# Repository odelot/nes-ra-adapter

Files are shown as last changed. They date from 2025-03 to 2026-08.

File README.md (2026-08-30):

# NES RA Adapter Project


Repository of the **NES RetroAchievements Adapter** project – a maker initiative with a "cyberpunk western" style that transforms the physical NES console (released in 1985) by adding Internet connectivity and achievement functionality, supported by the amazing RetroAchievements community.

<p align="center">
  <a href="https://youtu.be/u1GWOFgOU88">
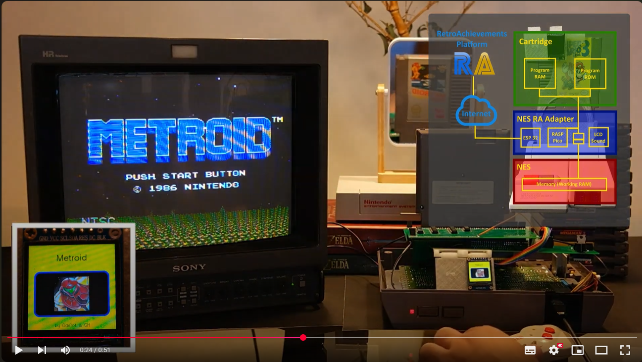
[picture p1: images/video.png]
    
  </a>
</p>

**Now you don't need to open your console!!!**

<p align="center">  
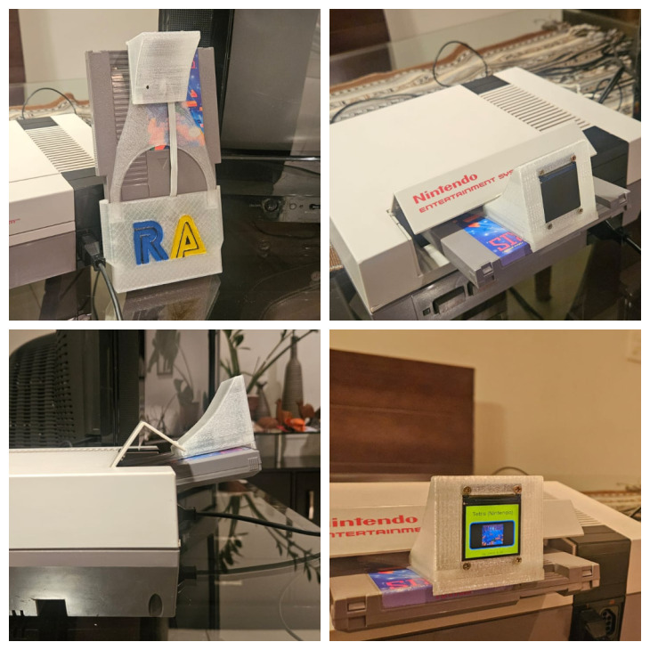
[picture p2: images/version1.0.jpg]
      
</p>

**Famicom version by mi213!**

<p align="center">  
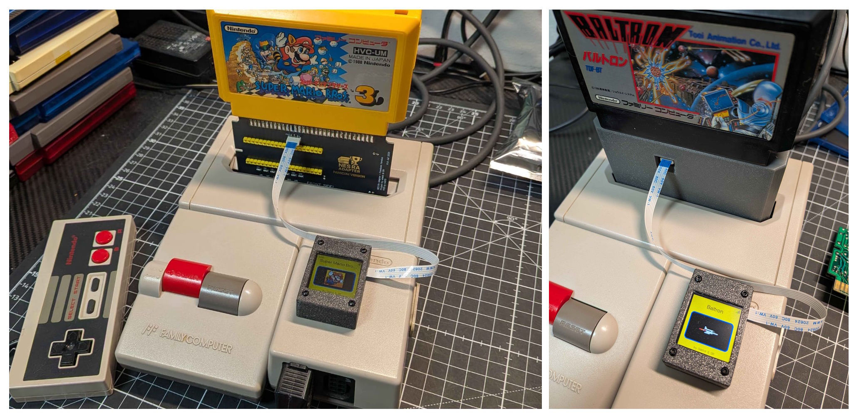
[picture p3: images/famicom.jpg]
      
</p>

---

## Table of Contents

- [Disclaimer](#disclaimer)
- [Introduction](#introduction)
- [Getting Started (How to Build)](#getting-started--how-to-build)
- [Architecture and Functionality](#architecture-and-functionality)
- [Limitations](#limitations)
- [General Information](#general-information)
- [Version History](#version-history)
- [Contributions](#contributions)
- [License](#license)
- [FAQ](#faq)
- [Acknowledgments](#acknowledgments)
- [Similar Projects](#similar-projects)

---

## Disclaimer

The project is not responsible for any use or damage it may cause. Build and use it at your own risk. This is a **PROTOTYPE** that works but still needs to evolve into a final version—with revised hardware, extensive testing, and easy replication. We want everyone to be able to build and use this prototype, but only attempt it if you know what you're doing.

---

## Introduction

The **NES RA Adapter** transforms your original NES console into an interactive, Internet-connected machine, allowing real-time achievement unlocking through the RetroAchievements platform. Inspired by the Game Genie with a touch of cyberpunk western, the adapter:
- **Identifies the game** by reading the cartridge (via CRC calculation).
- **Monitors the console's memory** to detect events and achievements.
- **Provides connectivity and interface** through a TFT screen, buzzer, and smartphone configuration.

### Repository Organization

- **nes-pico-firmware**: source code for the firmware used on the Raspberry Pi Pico (Chinese purple board).
- **nes-esp-firmware**: source code for the firmware used on the ESP32 C3 Super Mini.
- **hardware**: schematics and Gerber files for the v1.0 boards (NES 72-pin by GH and Famicom 60-pin by mi213), plus the old v0.1/v0.2 prototype PCBs used during development.
- **3d parts**: STL files for the modeled case, inspired by the Game Genie (NES 72-pin and Famicom 60-pin designs).
- **misc**ellaneous: auxiliary tool and files (LCD mirror Web App / CRC32<->RA Hash map creator / AWS Lambda to shrink RA response / TFT config).

---

## Getting Started / How to Build

### Acquire the Parts

#### Board 1

| Part Name | Quantity | 
|---|---|
| NES 72-pin slot* | 1x |
| SN74LVC1G3157DBVR | 26x |
| Raspberry Pi Pico (purple board) | 1x |
| Flat cable 20cm 1mm reverse 5pin | 1x |
| FFC & FPC Connectors 1.0 FFC Non ZIF SMT 5 pin - MOLEX 52808-0570 | 1x |
| PCB set | 1x |
| Electrolytic capacitor 10µF 16V | 3x |

\* for the Famicom board, use a 60-pin slot instead

#### Board 2 - PTH (Pin Through-Hole)

| Part Name | Quantity |
|---|---|
| ESP32 C3 Supermini PLUS (with external antenna) | 1x |
| 1.3 inch LCD 240x240 ST7789 with 7 pins | 1x |
| Passive Buzzer 16 ohms ac/2khz + Transistor BC548 | 1x |
| FFC & FPC Connectors 1.0 FFC Non ZIF SMT 5 pin - MOLEX 52808-0570 | 1x |
| PCB set | 1x |
| Electrolytic capacitor 10µF 16V | 1x |
| 1k ohm resistor (R1) | 1x |
| 10k ohm resistor (R2) | 1x |
| Push Button Switch 6x6x6 | 1x |
| 90º degree female header pins (to connect the LCD 7 pins) | 1x |
| 100 ohm resistor (R3 and R4) - optional | 2x |
| Bi-color LED (Green / Red, Common Cathode) - optional | 1x |

#### Board 2 - SMD (Surface Mount Device)

This is the alternative board 2 designed by mi213. It is the one required by his 3D case designs. See the BOM with the SMD components [here](<hardware/Famicom - v1.0 - by mi213/BOM-board2-famicom-v1.0 - by mi213.csv>) (the same board 2 is used by the NES and the Famicom versions).

#### 3d parts 

| Part Name | Quantity |
|---|---|
| 3d printed parts | 1x |
| M2 screw 6mm flat head with nut | 10x |
| M2 screw 10mm cylinder head | 4x |
| M2 length 3 mm (3.2 mm OD) heat-set inserts (for mi213 design) | 4x |

The STL files are in [3d-parts/STL/](3d-parts/STL/), organized by console and designer:
  - [NES - 72pin / 20250911 - odelot design](<3d-parts/STL/NES - 72pin/20250911 - odelot design>) → front-loader and top-loader cases for the through-hole board 2
  - [NES - 72pin / 20260811 - mi213 design](<3d-parts/STL/NES - 72pin/20260811 - mi213 design>) → front-loader and top-loader cases, require mi213's SMD board 2
  - [Famicom - 60pin / 20260811 - mi213 design](<3d-parts/STL/Famicom - 60pin/20260811 - mi213 design>) → Famicom case, requires mi213's SMD board 2

The heat-set inserts are only needed for the mi213 designs.

### Assemble the Circuit

Starting from version 1.0, thanks to GH’s custom boards, you no longer need to open your console to use the adapter. Combined with the 3D-printed case I designed, the adapter works just like a GameGenie,  simply plug it into the cartridge slot and you’re ready to go. A dedicated case for the top-loader model is also available.

Since 2026-08 there is also a **Famicom (60-pin) version of the boards and improved case designs, made by mi213** thanks! ❤️ The hardware files are organized like this:
  - [hardware/NES v1.0 - by GH/](<hardware/NES v1.0 - by GH>) → Gerbers for the NES 72-pin boards 1 and 2
  - [hardware/Famicom - v1.0 - by mi213/](<hardware/Famicom - v1.0 - by mi213>) → Gerbers for the Famicom 60-pin boards 1 and 2, plus the SMD BOM for board 2
  - [hardware/schematics/](hardware/schematics/) → schematics for board 1 and board 2

**Assembly Video Guide (with timecode)** - [https://www.youtube.com/watch?v=4uHbj2ckqv0](https://www.youtube.com/watch?v=4uHbj2ckqv0)
<br/>&nbsp;&nbsp;&nbsp;&nbsp; **\\-** Be sure to watch how the Pico needs to be soldered to avoid issues with the 3D-printed case.
<br/>&nbsp;&nbsp;&nbsp;&nbsp; **\\-** I printed my case using PLA, with three walls and infill ranging from 30% to 100%. You’ll need to use supports for the Board 2 case.

The adapter is built from two PCBs connected by a flat cable:

  - **Main board**: houses 26 SMD analog switches (the most challenging part of soldering), a purple Raspberry Pi Pico RP2040, the cartridge slot, flat cable connector, and a few coupling capacitors.
  - **Secondary board**: includes an ESP32 C3 Supermini, ST7789 LCD display, flat cable connector, buzzer, transistor, coupling capacitor, 10k and 1k resistors, plus an optional bi-color LED (green/red) with two 100 ohm resistors, which can also be used as an alternative to the LCD.

**About PCB Thickness** - NES cartridge PCBs have a board thickness of 1.2mm, while the GameGenie has 1.6mm. After some tests, here is the deal:
  - **NES Front Loader**: order the PCB with a thickness of 1.6mm like GameGenie
  - **NES/Famicom Top Loader**: order the PCB with a thickness of 1.2mm like a original NES Cartridge    

You’ll find everything you need to build it yourself:
  - /hardware → schematic and Gerber files for PCB production (NES and Famicom)
  - /3d-parts → STL files for the front-loader, top-loader and Famicom cases

### Update the Pico and ESP32 Firmware

1. Download the firmwares from the *Releases* section.
   
2. **Raspberry Pi Pico** - Connect the Pico to the computer via USB while holding the BOOTSEL button. A folder will open on your desktop. Copy the `nes-pico-firmware.uf2` file to this folder. This [guide](https://www.youtube.com/watch?v=os4mv_8jWfU) can help you understand the process.
   
3. **ESP32 C3 Supermini** – You'll need to install esptool. Here’s a [guide](https://docs.espressif.com/projects/esptool/en/latest/esp32/installation.html#installation). If you're using the Arduino IDE with ESP32, you already have it installed.
   - First, identify the COM port assigned to the ESP32 when connected via USB (in this example, it's COM11).
   - Open the command line, navigate to the nes-esp-firmware folder inside the release files, and run the following commands (change the COM port accordingly). On Linux/macOS use `esptool.py` (or `python -m esptool`) and a port like `/dev/ttyUSB0`:

```
esptool.exe --chip esp32c3 --port "COM11" --baud 921600  --before default_reset --after hard_reset write_flash  -z --flash_mode keep --flash_freq keep --flash_size keep 0x0 "nes-esp-firmware.ino.bootloader.bin" 0x8000 "nes-esp-firmware.ino.partitions.bin" 0xe000 "boot_app0.bin" 0x10000 "nes-esp-firmware.ino.bin" 

esptool.exe --chip esp32c3 --port COM11 --baud 921600 --before default_reset --after hard_reset write_flash -z --flash_mode dio --flash_freq 80m --flash_size detect 0x210000 ra_rash_map.bin
```

The second command writes the CRC32↔RA-hash map (`ra_rash_map.bin`) into the LittleFS partition at offset `0x210000`

## Architecture and Functionality

The adapter uses two microcontrollers working together:

<p align="center">
  
</p>

### Raspberry Pi Pico

- **Game Identification:** Reads part of the cartridge to calculate the CRC and identify the game.
- **Memory Monitoring:** Uses two cores to monitor the bus and process writes using the rcheevos library:
  - **Core 0:** Calculates the CRC, runs rcheevos routines, and manages serial communication with the ESP32.
  - **Core 1:** Uses four PIO state machines (no DMA): one captures exactly one bus snapshot per CPU write cycle and keeps static mirrors of the NES RAM and cartridge SRAM up to date; one watches the CPU fetching the NMI vector ($FFFA/$FFFB) to mark the exact start of vblank; one watches the RESET vector ($FFFC/$FFFD) to detect console resets; and one runs a frame timer that, together with writes to $4014 (OAM DMA), acts as a fallback for games that run with NMI disabled. At each vblank, core 1 takes an atomic snapshot of the memory mirrors and signals core 0 to run a rcheevos frame.
- **Note:** During game load the Pico reserves ~100KB of RAM for the achievement list response; the buffer is shrunk once the game starts.

### ESP32

- **Connectivity and Interface:** Provides Internet to the NES and manages a TFT screen to display achievements, along with a buzzer for sound effects.
- **Configuration Management:** Stores Wi-Fi and RetroAchievements credentials in EEPROM; configuration is done via smartphone connected to the ESP32 access point.
- **File System and Communication:** Uses LittleFS to store a hash table (CRC32 to MD5) for cartridge identification and game images.
- **Streams LCD content to a Web App** - Uses WebSocket and mDNS to serve a web app that mirrors the LCD display and shows additional achievement events that don’t fit on the physical screen. (More details available in the `misc` folder.) The web app becomes available as soon as the game image appears on the LCD and can be accessed at `http://nes-ra-adapter.local`, make sure your smartphone is connected to the same Wi-Fi network.

---

## Limitations

- **Server Response Size:** During game load the Pico reserves ~100KB of RAM for the RetroAchievements response. The ESP32 cleans the response while it is still being downloaded, so raw payloads bigger than that are supported (FF3, for example, goes from 129KB raw to ~83KB clean). Before sending the set to the Pico, the ESP32 also estimates the peak heap the Pico will need to load it; when the estimate goes over the budget (~168KB), it drops the rich presence first and then the most expensive achievements (achievements flagged as *progression* or *win_condition* are always kept) so the game can still be beaten. The source code of an AWS Lambda function is also available (misc folder) if you prefer to shrink the response server-side.

- **Rare Limitation: Some Games May Be Unmasterable** A single achievement with an extremely large definition can exceed the Raspberry Pi Pico's RAM when expanded by the rcheevos library (one Final Fantasy achievement alone expands to ~140KB of runtime structures, more than the RP2040 can hold together with everything else). So far this affects FF1 and FF3 (in FF3, 8 achievements have to be dropped for the set to fit, so the game can be beaten but not mastered). A future hardware revision based on the RP2350 (520KB of RAM) will remove this limit.

- **Leaderboards are disabled** To shrink data between ESP32 and Pico, the leaderboard feature is disabled. Now that frame detection is precise (v1.4), enabling leaderboards is on the roadmap.

---

## General Information

- **Power Consumption:** The adapter typically consumes 0.105A (max ~0.220A). The LCD screen consumes about 0.035A. Consumption is within the limit of the 7805 voltage regulator present in the NES

- **Logic Level Conversion (5V vs 3.3V):** The prototypes do not use logic level conversion to avoid signal delays. The bus between the cartridge and the NES is disabled when identifying the cartridge (not affecting the NES), and current levels are within Pico’s limits. In the final version, current limiting will be considered to reduce stress on the Pico. If someone in the community identifies the need for level shifting and develops a test scheme without compromising signals, contributions are welcome.

---

## Version History

- **Version 1.4 (2026-08-30)**
  - Famicom PCBs and 3d printed cases by mi213 \o/
  - Complete rewrite of the bus monitoring engine on the Pico: the PIO now captures exactly one sample per CPU write cycle (replacing ~10x oversampling and the stable-value heuristic), DMA and its ping-pong buffers were removed (~16KB of RAM freed), and core 1 drains the PIO FIFOs directly with much lower latency.
  - Precise vblank detection: a dedicated PIO state machine watches the CPU fetching the NMI vector ($FFFA/$FFFB), marking the exact start of vblank, validated on real hardware at 60.099Hz with ±5µs jitter. Games that never do OAM DMA (e.g. Mike Tyson's Punch-Out!!) are now frame-accurate instead of relying on simulated frames. Writes to $4014 and a timer remain as fallbacks for games running with NMI disabled.
  - Console RESET detection via the RESET vector ($FFFC/$FFFD): pressing the console reset button now resets the rcheevos runtime state (hit counts, indicators), the same way emulators do, no more power cycling.
  - Truly atomic RAM snapshots: memory snapshots are taken at vblank start with write staging, guaranteeing point-in-time consistency for achievement evaluation.
  - Fixes for known bugs (credentials management)
- **Version 1.3 (2026-05-15)**
  - Major RAM usage optimization on the Pico: the circular memory buffer was replaced by static mirrors of the NES RAM and cartridge SRAM with atomic snapshots taken during OAM DMA.
  - The serial buffer is now allocated dynamically: ~100KB during the achievement list download (up from 32KB), shrunk after the game loads, supporting much larger achievement sets.
  - Includes the fixes released in the 1.2-alpha build.
- **Version 1.2-alpha (2026-05-04)** - New frame detection heuristic and a fix for the cartridge reading problem affecting Castlevania.
- **Version 1.1 (2026-02-01)** 
  - Major RAM usage optimization on the ESP32 (over 40% savings), increasing the maximum payload size and allowing support for more games, including Super Mario Bros. 3, which became unsupported in version 1.0 after receiving additional achievements at the end of 2025.
  - Added a progress indicator in the upper-left corner of the screen (earned achievements / total achievements) and a Wi-Fi signal strength indicator in the upper-right corner.
  - Implemented a celebration routine when a game is mastered.
  - Fixed minor bugs. The console no longer needs to be powered off and on again after configuring the adapter.
- **Version 1.0 (2025-09-11)** - New miniaturized board and 3d case available - no need to open up the console. Minor changes in the frame detection heuristic. Optional Bicolor Status LED as an option to the LCD. Option to flip the LCD content (needed for the 1.0 case assembly)
- **Version 0.7 (2025-07-09)** - Changes to the frame detection heuristic, using microseconds instead of milliseconds and doing frame skipping if necessary to stay as close as possible to the 60hz cadence (or 50hz, when handling a DEFINE during compilation).
- **Version 0.6 (2025-06-25)** - Bug fix in serial comm on ESP32, "show password" feature for RA credentials during setup, filtering of some achievements directly in the RA API.
- **Version 0.5 (2025-06-24)** - Hardcore mode enabled. LED status in a semaphore way (green, yellow, red) to make the LCD optional. Minor bug fixes.
- **Version 0.4 (2025-05-15)** - Make the experimental mirror screen feature more stable on pico firmware. Releases an Android App (APK - release section) to help on the usage of the mirror screen feature.
- **Version 0.3 (2025-04-24)** – Improve error handling, optimize ram usage, deployed an experimental feature to stream the content of the tiny LCD to a smartphone
- **Version 0.2 (2025-04-07)** – Optimizations to reduce energy consumption.
- **Version 0.1 (2025-03-28)** – Initial prototype version.

---

## Contributions

Everyone is welcome to contribute!
- Submit improvements and pull requests via GitHub.
- Join our Discord channel: [https://discord.com/invite/6eYGq7NNfF](https://discord.com/invite/6eYGq7NNfF)
- Support us by [buying a coffee](https://buymeacoffee.com/nes.ra.adapter) or [Patreon](https://www.patreon.com/RetroAchievementsHardwareLab) .

---

## License

- This project source code is distributed under the **GPLv3** license.
- The PCB circuits are distributed under **CC-BY-4.0** license.
- The 3d parts are distributed under **CC-BY-NC-4.0** license.

---

## FAQ

- **Q: Are you planning to sell the adapter?**
- **A**: No. This is a fully open-source, community-driven DIY project.
<br/>

- **Q: So how can I get one?**
- **A**: It's a DIY project, you can build it yourself!
If you're not comfortable doing that, don’t worry: as seen with other open-source projects like the [GBSControl](https://github.com/ramapcsx2/gbs-control), [GB Interceptor](https://github.com/Staacks/gbinterceptor) and [Open Source Cartridge Reader](https://github.com/sanni/cartreader), the community often steps in to produce and sell units for those who don’t want to build their own. Also, the guy that mods your console is very capable of building one for you.
<br/>

- **Q: Do I need to modify my NES in any way?**
- **A**: No. The adapter is plug-and-play and doesn’t require any console modification.
<br/>

- **Q: Do I need to connect it to a computer?**
- **A**: No! It’s fully self-contained with built-in Wi-Fi.
If you ever need to configure it, you can do so from your smartphone. All achievement processing is handled onboard.
<br/>

- **Q: Will the adapter work with EverDrives?**
- **A**: No. The adapter needs to read the cartridge to identify the game, but when using an EverDrive, it reads the EverDrive’s firmware instead of the game itself. That’s one of the reasons why supporting EverDrives is not currently possible.
<br/>

- **Q: Will it work with Japanese Famicom systems?**
- **A**: Yes, mi213 designed a Famicom (60-pin) version of the boards and a matching 3D-printed case (see the `hardware` and `3d-parts` folders). The NES version also works with 72-to-60 pin adapters: many Japanese games are already mapped on RetroAchievements, and we’ve successfully tested some using a 60-to-72 adapter.
<br/>

- **Q: Will it work with the Disk System?**
- **A**: We haven’t tested with the Disk System since we don’t have one. It’s a possible future enhancement if we can get the hardware for testing.
<br/>

---

## Acknowledgments

- Thanks to **RetroAchievements** and its community for providing achievements for nearly all games and making the system available to everyone.
- Thanks to **NESDEV** for detailed NES documentation and a welcoming forum.
- Thanks to **GH** for the v1.0 NES boards that made the plug-and-play adapter possible, and to **mi213** for the Famicom v1.0 boards and the improved 3D case designs.
- People that helped us during the donation campaign (April/25) - **THANK-YOU**:
  - Aaron P.
  - Stupid C. G.
  - Elaine B.
  - I F. S.
  - Ken G.
  - Kaffe S.
  - Jonathan
  - Sharon L.
  - Daniel P.
  - Ricardo S. S.
  - Fabio H. A. F.
  - Anuar N.
  - Bryan D. S.
  - Giovanni M. C.
  - Paulo H. A. S.
  - Fernando G. S.
  - Rafael B. M.
  - Thiago G. O.
  - Jerome V. V.
  - Ricardo V. A. M.
  - Tiago T.
  - Leonardo P. K.
  - Fábio S.
  - Anderson A. B.
  - Rubens M. P.
  - Silvio L.
  - Carlos R. S.
  - Ademar S. J.
  - Marcel A. B. C.
  - Peterson F. I.
  - Denis D. F. F.
  - Luis A. S.
  - Ariovaldo P.
  - Theo M. O. C. P.
  - Thiago P. L.
  - André R.

## Similar Projects

- **RA2SNES**: [https://github.com/Factor-64/RA2Snes](https://github.com/Factor-64/RA2Snes) - RA2Snes is a program built using Qt 6.7.3 in C++ and C that bridges the QUsb2Snes webserver & rcheevos client to allow unlocking Achievements on real Super Nintendo Hardware through the SD2Snes USB port.

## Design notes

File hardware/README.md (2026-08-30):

# Circuit Schematics and PCB

## Version 1.0 - NES

Finally you can use the adapter without opening your NES. Order the PCB, assemble it and be happy ;-) Made by the awesome GH.

<p align="center">
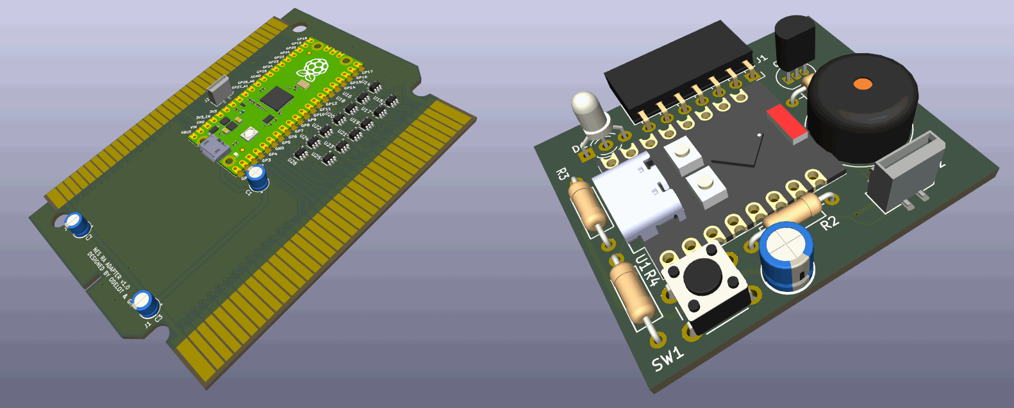
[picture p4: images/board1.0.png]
  
</p>

<p align="center">
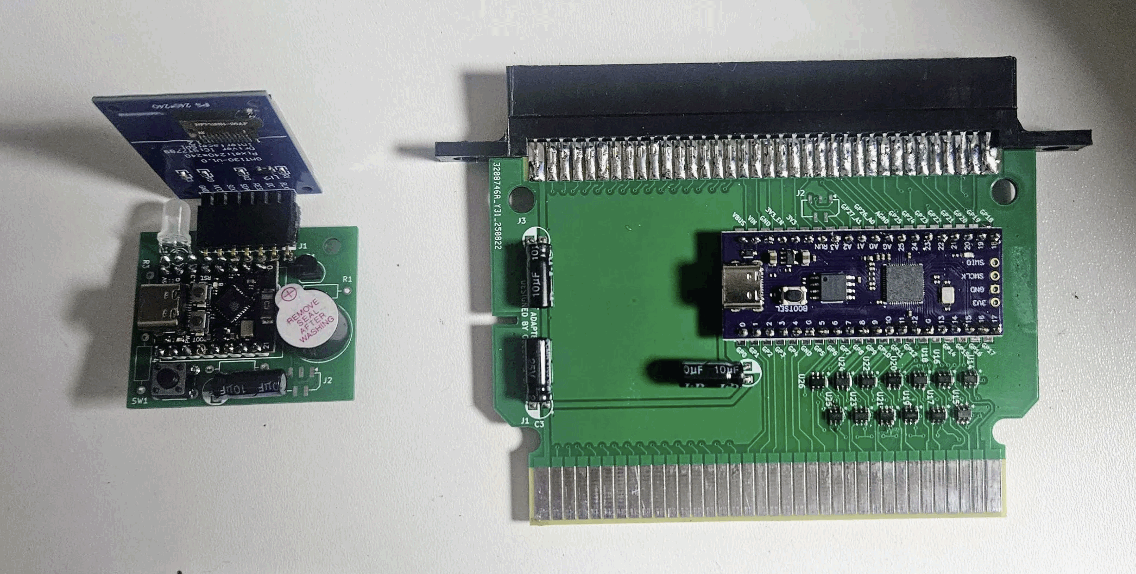
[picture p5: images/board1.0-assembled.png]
  
</p>

Schematics:

<p align="center">
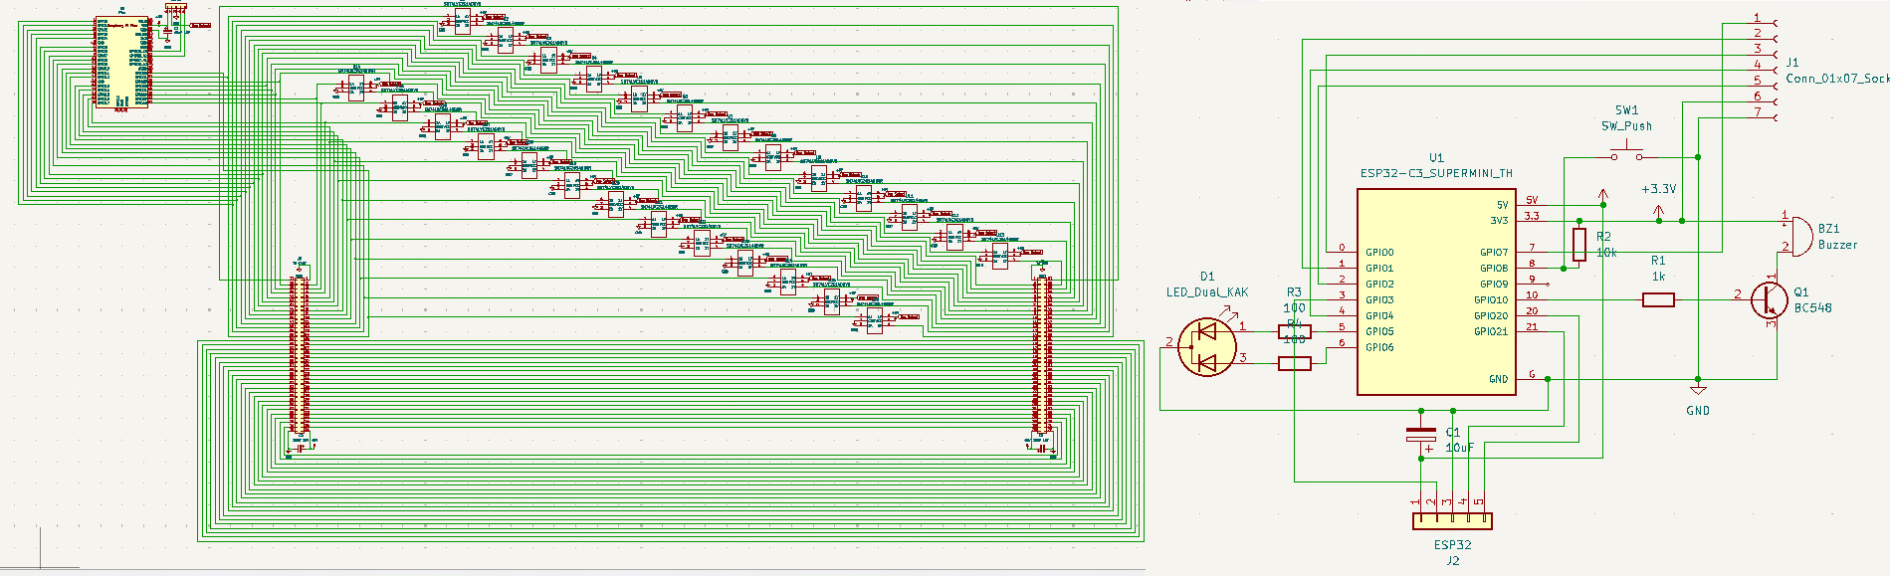
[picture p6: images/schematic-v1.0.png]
  
</p>

## Version 1.0 - Famicom

There is also a Famicom version made by mi213 - Thanks! ❤️

## Prototype PCBs Sets 

We have two sets of PCBs used for development, implementing the minimal schematic shown above. Each has its pros and cons, but both feature large traces (which isn't ideal) and lack a ground plane. These were designed purely for development purposes. All prototype PCBs were created using Fritzing version 0.9.3b by odelot (a Computer Scientist—please forgive him for that! 😆).

Schematics:

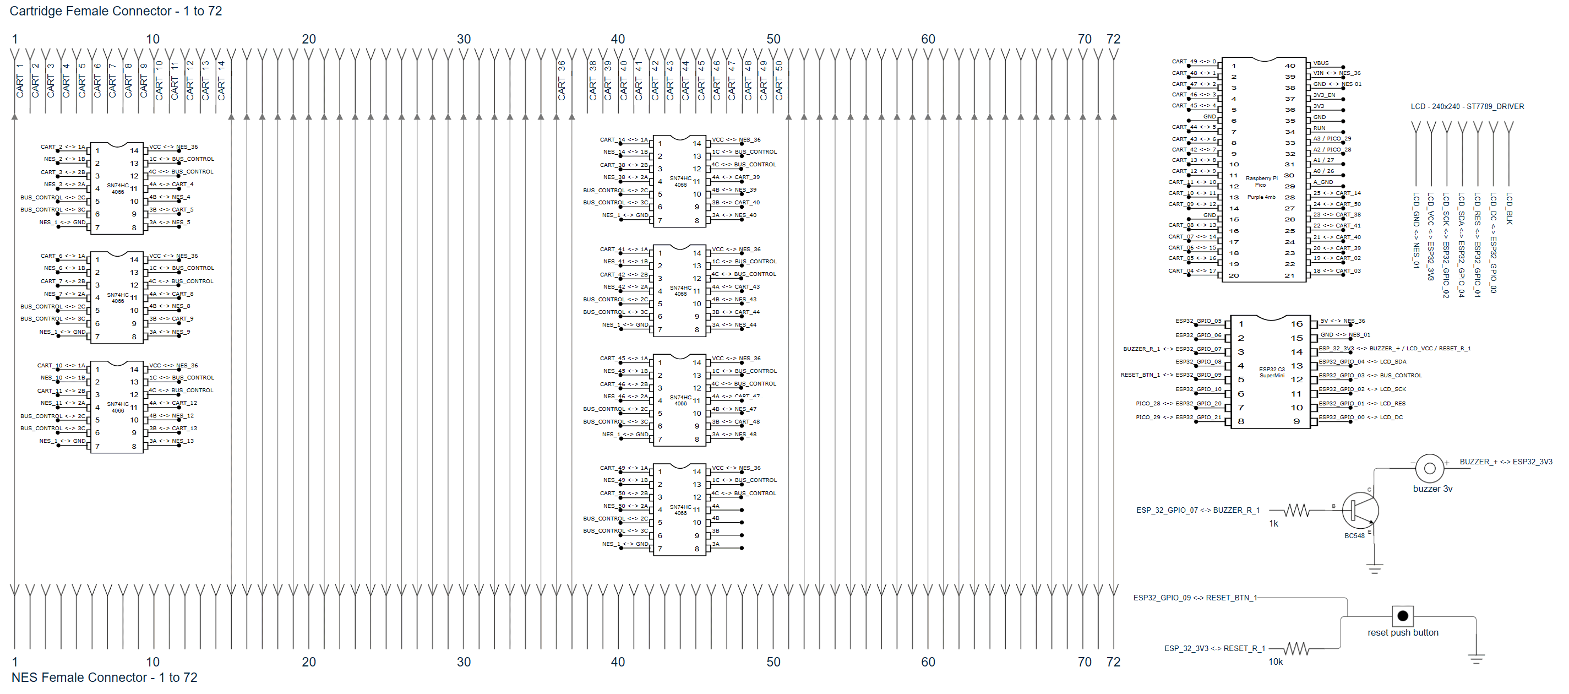
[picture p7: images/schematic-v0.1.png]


### Prototype v0.1

This set consists of four PCBs that can be connected like modules. You can remove one of them to test new ideas, such as swapping out the SN74HC4066 board for bus transceivers or inserting a logic level shifter between two modules. Female headers can be used to easily attach logic analyzers or oscilloscopes for debugging.

The PPU signal traces are relatively small, but the CPU signal traces are large to accommodate debugging and flexibility. Since the boards are connected using 90-degree headers, they can sometimes suffer from poor contact, requiring plastic supports to keep them level. Games with MMC3 may experience issues with the scanline detector due to the large trace sizes and the propagation delay introduced by the 4066.

<p align="center">
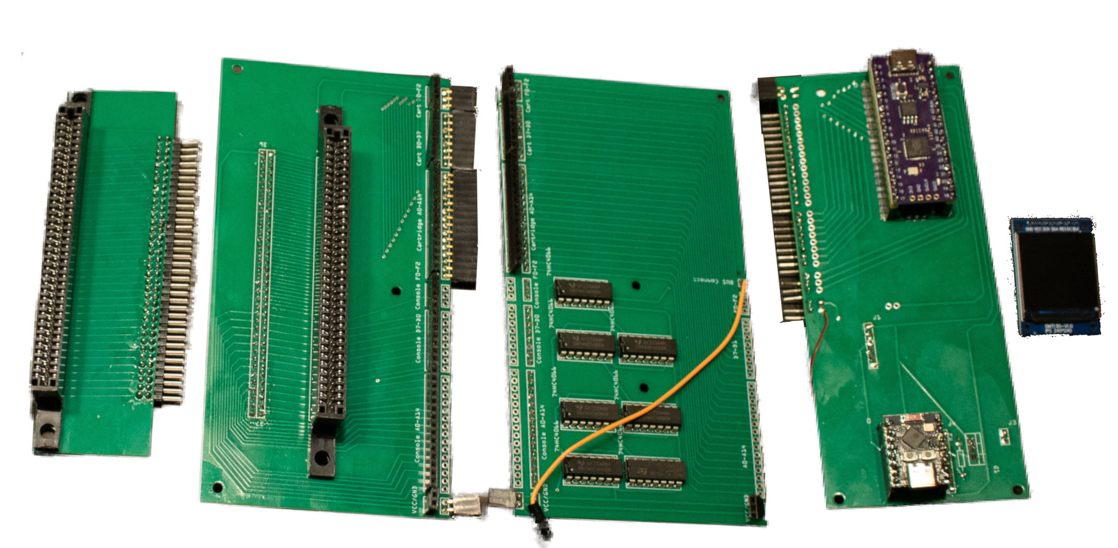
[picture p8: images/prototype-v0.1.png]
  
</p>

### Prototype v0.2

To address contact issues, we created an almost all-in-one design (in a rush, right before a big vacation, to avoid waiting nearly 30 days for fabrication—we could've done it better!). The PPU traces are too large, which can cause interference on certain NES motherboards (detected with NES-CPU-02 and Rad Racer).

This version consists of two boards, similar to what we aim for in the miniaturized version:

- One board with the 4066s and the Raspberry Pi Pico.
- Another board with the ESP32, LCD screen, reset button, and buzzer.

With these two boards, we can experiment with different communication methods using flat cables already aiming the final version. MMC3 scanline detector issues are minimal with the 4066, and completely eliminated when using the SN74LVC1G3157DBVR.

<p align="center">
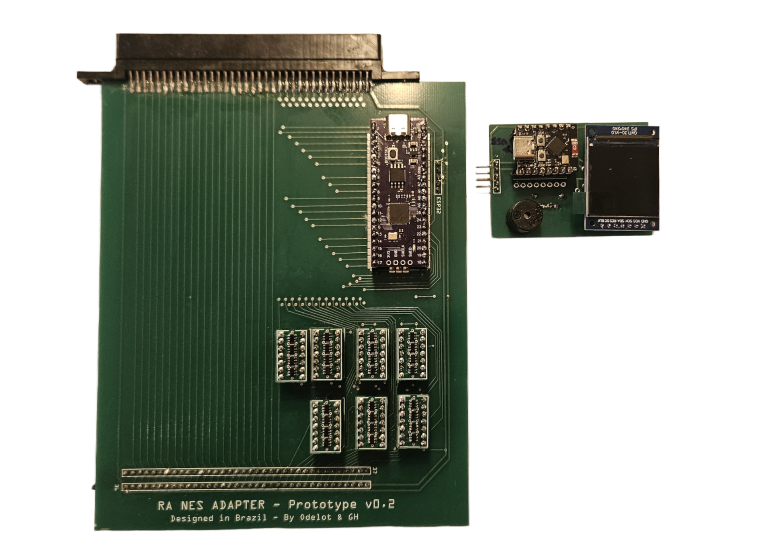
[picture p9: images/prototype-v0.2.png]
  
</p>

### SN74HC4066 vs SN74LVC1G3157DBVR

To minimize propagation delay issues, we designed an adapter that replaces the 4066 with a set of four SN74LVC1G3157DBVR chips. This completely resolved the MMC3-related problems. One thing to keep in mind: the SN74LVC1G3157DBVR is an SMD component and is more challenging to solder.

<p align="center">
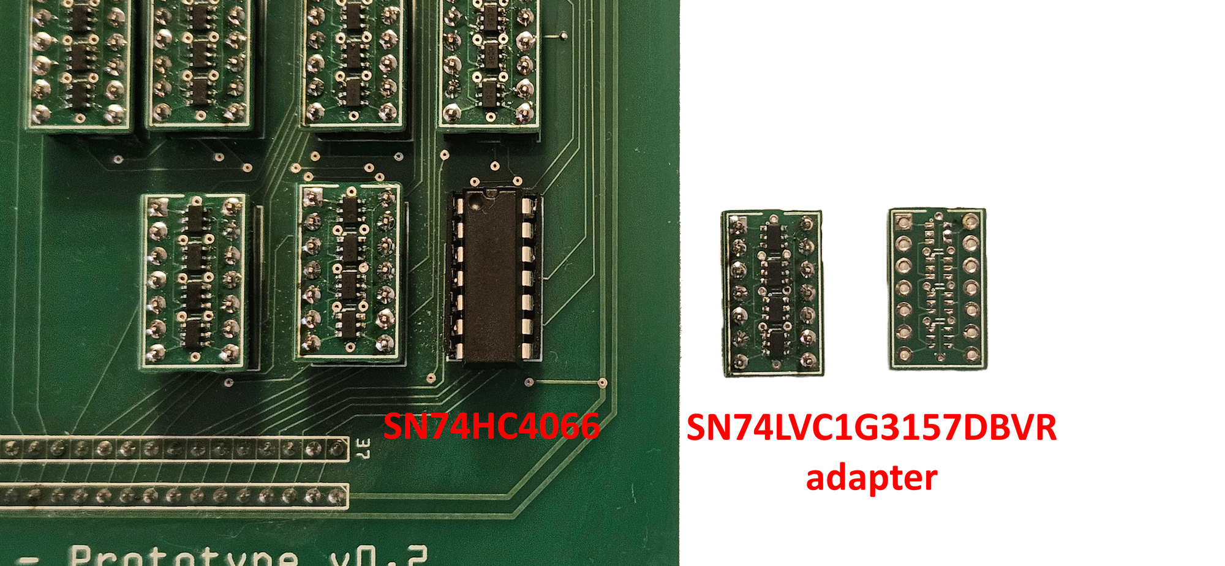
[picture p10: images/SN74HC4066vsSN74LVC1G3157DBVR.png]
  
</p>

## License

The PCB circuits are distributed under CC-BY-4.0 license.

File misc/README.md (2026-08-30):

# Miscellaneous

Here you'll find various files and tools to assist with using or developing for the adapter.

## Web App

This web app replicates the behavior of the adapter's tiny LCD screen, while displaying a bit more information — such as active challenges and achievement progress — similar to how it appears in emulators.

It connects to the ESP32 via WebSocket, enabling real-time communication. As soon as the ESP32 displays information on the physical LCD, it simultaneously sends the same data to any connected client through WebSocket.

A minified version of this web app can be found in the `data` folder of the `nes-esp-firmware` project to save flash space. The ESP32 serves the page using mDNS at:
http://nes-ra-adapter.local

Please note that it runs over HTTP (not HTTPS) because the firmware doesn't have enough free RAM to support SSL. This limitation also affects some HTML5 features — such as push notifications and the ability to keep the screen always on. If you're using a browser, you'll need to manually adjust your device's display settings to prevent it from turning off.

I’ve also started developing an Android app to overcome most of these HTTP limitations, but it’s not ready for release just yet.

## TFT_eSPI_config 

There is a config This file is required only if you plan to build the ESP32 firmware yourself. It configures the TFT screen for the ESP32 C3 Super Mini and must be copied into the TFT_eSPI library folder. 

There is also a fix for a bug to the latest version of TFT_eSPI that avoid ESP32 to boot loop. You can overwrite the folder `Processor` inside TFT_eSPI library folder. This [issue](https://github.com/Bodmer/TFT_eSPI/issues/3284) reports about this problem.

## crc-md5-mapper

We use a mapping system that links CRC values (calculated from a portion of the cartridge ROM) to their corresponding MD5 hashes, extracted from a ROM set. The [games.txt](https://github.com/odelot/nes-ra-adapter/blob/main/nes-esp-firmware/data/games.txt) file, located in `/nes-esp-firmware/data`, contains a precomputed version of this mapping, generated using this Python script and the GoodNES ROM set.

This can be useful if you want to understand how we compute MD5 hashes (RA Hashes) or if you need to add new entries to the map, such as homebrew games. For example, I personally added Micro Mages, which isn't included in the GoodNES ROM set.

## shrink-lambda-function

The list of achievements retrieved from the RA API is designed for emulators, not microcontrollers with limited RAM. Since version 1.4, the ESP32 cleans the response while it is still being downloaded (see `PatchStreamFilter.h`), so the raw payload never has to fit in RAM — only the cleaned result does (FF3, for example, goes from 129KB raw to ~83KB clean). The Pico reserves ~100KB for the achievement list during game load, and before sending the set the ESP32 estimates the peak heap the Pico will need; if it goes over the budget (~168KB), rich presence and the most expensive achievements are dropped, always keeping the ones flagged as *progression* or *win_condition*.

Even so, if you prefer to shrink the response server-side, or to control exactly which achievements are trimmed, you can deploy this Node.js Lambda function on AWS with an API Gateway in front of it. This setup acts as a proxy, reducing the response size by removing unnecessary fields—or, in extreme cases, trimming some achievements.

If you choose this approach (which I used extensively for testing), be sure to modify `nes-esp-firmware.ino` to enable it and set the Lambda URL. You'll also need to build and manually upload the modified firmware to the ESP32.

```
#define ENABLE_SHRINK_LAMBDA 1 // 0 - disable / 1 - enable
#define SHRINK_LAMBDA_URL "https://xxxxxxxxxx.execute-api.us-east-1.amazonaws.com/default/NES_RA_ADAPTER?" // your url
```

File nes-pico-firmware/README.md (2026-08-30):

# nes-pico-firmware

In this project, the Raspberry Pi Pico has two Main Responsibilities:

1. Game Identification: Reads a portion of the cartridge to calculate the CRC and identify the game.

2. Memory Monitoring: Monitors the bus for memory writes and processes them using the rcheevos library.

This is distributed between cores in the following:

- Core 0:
  - Handles CRC calculation.
  - Executes rcheevos routines.
  - Manages serial communication with the ESP32 (primarily for Internet connectivity).

- Core 1:
  - Monitors the bus using three PIO state machines (no DMA):
    - **SM0** captures exactly one bus snapshot per CPU write cycle (sampled inside the data-valid window of M2 high) and keeps static mirrors of the NES RAM and cartridge SRAM up to date.
    - **SM1** watches for reads of the NMI vector ($FFFA/$FFFB) — the exact start of vblank — when core 1 takes an atomic snapshot of the mirrors and signals core 0 to run a rcheevos frame.
    - **SM2** watches for reads of the RESET vector ($FFFC/$FFFD) to detect a console reset and reset the rcheevos runtime state.
  - Writes to $4014 (OAM DMA) are kept as a vblank fallback for games that run with NMI disabled, plus a timer-based fallback for forced-blank periods.

*Note:* During game load the serial buffer holds up to ~100KB for the achievement list response; it is shrunk to 16KB once the game starts, freeing RAM for the rcheevos runtime.

---

## 🔧 How to Compile the Project for Raspberry Pi Pico Using VS Code  

This guide explains how to set up and compile the firmware for the **Raspberry Pi Pico** using **VS Code** with **Pico SDK 1.5.1**. The project integrates the **[rcheevos](https://github.com/RetroAchievements/rcheevos)** library via **CMake**, which is automatically downloaded and configured during compilation.  

---

### 📌 Prerequisites  

- **Hardware:** Raspberry Pi Pico Purple Board
- **Software:**  
  - **VS Code** (with recommended extensions such as **C/C++** and **CMake Tools**)  
  - **Pico SDK 1.5.1** installed and configured  
- **Environment Setup:**  
  - Ensure the **`PICO_SDK_PATH`** environment variable is correctly set to point to the Pico SDK directory.  
- **Reference Guide:**  
  - Follow this tutorial: [Raspberry Pi Pico and RP2040 – Part 1: Blink and VS Code](https://www.digikey.com.br/en/maker/projects/raspberry-pi-pico-and-rp2040-cc-part-1-blink-and-vs-code/7102fb8bca95452e9df6150f39ae8422).  

---

### 🛠 Development Environment Setup  

1. **Clone the project repository** to your local machine
2. **Open the project in VS Code.**
3. **Ensure the development environment is properly configured:**
   - Confirm that PICO_SDK_PATH is correctly set in your system.
   - Install the necessary VS Code extensions (C/C++ and CMake Tools).

---

### ⚙️ CMake Configuration

- The project uses CMake as its build system.
- The rcheevos library is already configured in CMakeLists.txt and will be **automatically downloaded** during configuration and compilation.
- Check the `CMakeLists.txt` file to understand how the library and other dependencies are integrated.

---

### 🔨 Compiling the Project

1. Configure the Project:
   - Open the Command Palette in VS Code (Ctrl+Shift+P) and select CMake: Configure to initialize the project.

2. Build the Project:
   - Once configured, use CMake: Build to compile the firmware.
   - If everything is set up correctly, the build process will generate a .uf2 file in the output directory.

---

### 🚀 Flashing the Firmware to the Raspberry Pi Pico

1. Connect the Raspberry Pi Pico:
   - Plug the Pico into your computer while holding down the BOOTSEL button.

2. Copy the UF2 File:
   - The Pico will appear as a USB storage device. Simply drag and drop the .uf2 file onto this drive to flash the firmware.

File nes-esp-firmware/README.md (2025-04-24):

# nes-esp-firmware

We chose the **ESP32 C3 Super Mini model**. In the project it:

- Provides Internet connectivity to the NES.
- Manages a TFT screen to display unlocked achievements.
- Controls a buzzer for sound effects.
- Stores Wi-Fi and RetroAchievements (RA) credentials in EEPROM.
- Allows configuration via smartphone, connecting to the ESP32's access point.
- Supports configuration reset by holding the reset button for 5 seconds during startup.
- Uses LittleFS to store:
  - A CRC32-to-MD5 hash table (for cartridge identification).
  - Game and achievement images.
- Communicates with the Raspberry Pi Pico via Serial0 to:
  - Retrieve the game CRC.
  - Send HTTP requests to RetroAchievements.
  - Receive and forward HTTP responses.
- Controls analog switches to open and close the bus between the NES and the cartridge.

---

## 🔧 How to Compile the Firmware for ESP32-C3 Super Mini  

This guide explains how to set up **Arduino IDE (version 2.3.4)** to compile and upload the firmware to an **ESP32-C3 Super Mini**.  

---

### 📌 Prerequisites  

1. **Download and install Arduino IDE (2.3.4)**  
   - Get it from: [https://www.arduino.cc/en/software](https://www.arduino.cc/en/software)  

2. **Install ESP32 board support in Arduino IDE**  
   - Open **Arduino IDE**  
   - Go to **Tools** → **Board** → **Board Manager**  
   - Search for **esp32** and install the version `v3.0.7` of **ESP32 by Espressif Systems**  
   - Once installed, select **ESP32C3 Dev Module** under **Tools** → **Board**  

3. **Install the required libraries**  

   The project uses the following libraries, which you can install via the **Library Manager** or manually from GitHub:  

   - **WiFiManager** (v2.0.17) → [https://github.com/tzapu/WiFiManager](https://github.com/tzapu/WiFiManager)  
   - **PNGdec** (v1.1.2) → [https://github.com/bitbank2/PNGdec](https://github.com/bitbank2/PNGdec)  
   - **TFT_eSPI** (v2.5.43) → [https://github.com/Bodmer/TFT_eSPI](https://github.com/Bodmer/TFT_eSPI)
   - **ESP Async WebServer** (v.3.7.6) -> [https://github.com/ESP32Async/ESPAsyncWebServer](https://github.com/ESP32Async/ESPAsyncWebServer)
   - **Async TCP** (v3.4.0) -> [https://github.com/ESP32Async/AsyncTCP](https://github.com/ESP32Async/AsyncTCP)

   **To install via Library Manager:**  
   - Open **Tools** → **Library Manager**  
   - Search for the library name and click **Install**  

4. **Install the Arduino LittleFS Upload Plugin**

   Visit the [plug-in site](https://github.com/earlephilhower/arduino-littlefs-upload) and follow its instructions. This is used to upload the contains of `data` folder (the CRC32<->MD5 map) to the LittleFS.

---

### ⚙️ TFT_eSPI Library 

Copy the files from `miscellaneus/TFT_eSPI_config` into the library folder (usually `/user/Documents/Arduino/libraries/TFT_eSPI`). It contains the user settings for the LCD we are using and also a bugfix for the version of the library we are using.

### ⚙️ Configuring Arduino IDE for ESP32-C3  

Before compiling, adjust the settings in Arduino IDE:  

1. **Go to** Tools → Board → **ESP32C3 Dev Module**  
2. Configure the following options:  

   - **USB CDC On Boot**: Enabled
   - **CPU Frequency**: 80MHz (WiFi)
   - **Core Debug Level**: None  
   - **Erase All Flash Before Sketch Upload**: Disabled  
   - **Flash Size**: 4MB (32Mb)  
   - **Partition Scheme**: No OTA (2MB APP/2MB SPIFFS)   
   - **Upload Speed**: 921600  

---

### 🚀 Compiling and Uploading to ESP32-C3  

1. **Connect the ESP32-C3** to your PC via USB  
2. **Select the correct port** under **Tools** → **Port**  
3. **Compile the code** by clicking the ✔️ (Verify) button  
4. **Upload the firmware** to the ESP32 by clicking the 🔼 (Upload) button  
5. **Upload the data** using the Arduino LittleFS Upload plug-in. `[Ctrl]` + `[Shift]` + `[P]`, then "Upload LittleFS to Pico/ESP8266/ESP32".

If everything is set up correctly, the firmware will be flashed, and the ESP32-C3 will be ready to run the project!  

---

### ❓ Troubleshooting  

If you encounter issues:  
- **Check the IDE console for errors** and ensure all required libraries are correctly installed.  
- **Confirm the correct board and port** are selected in the Arduino IDE.  
- **Try using a different USB cable or port** if the ESP32 is not detected.  
- **Press the "Boot" button on the ESP32-C3 during upload** if flashing fails.  
- **If you couldn't upload the data folder using the plug-in** follow the Troubleshooting found on the [plug-in site](https://github.com/earlephilhower/arduino-littlefs-upload).

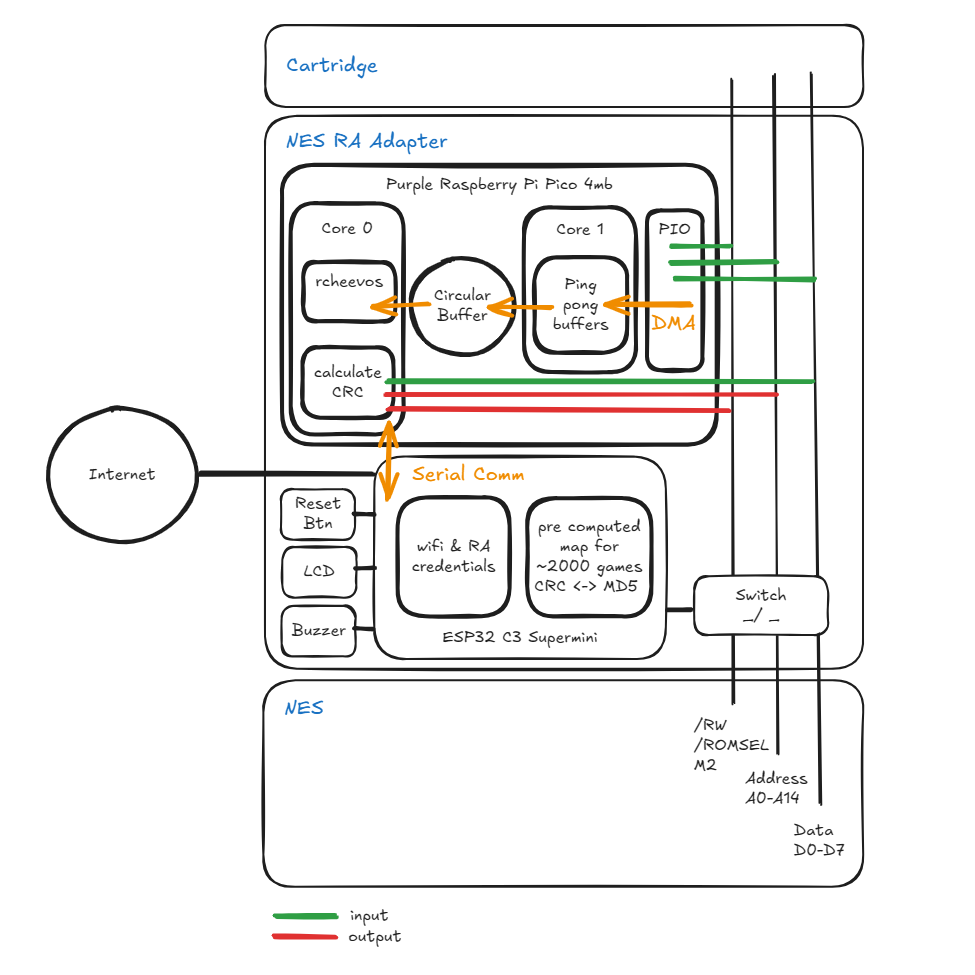
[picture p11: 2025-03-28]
images/architecture-v1.0.png

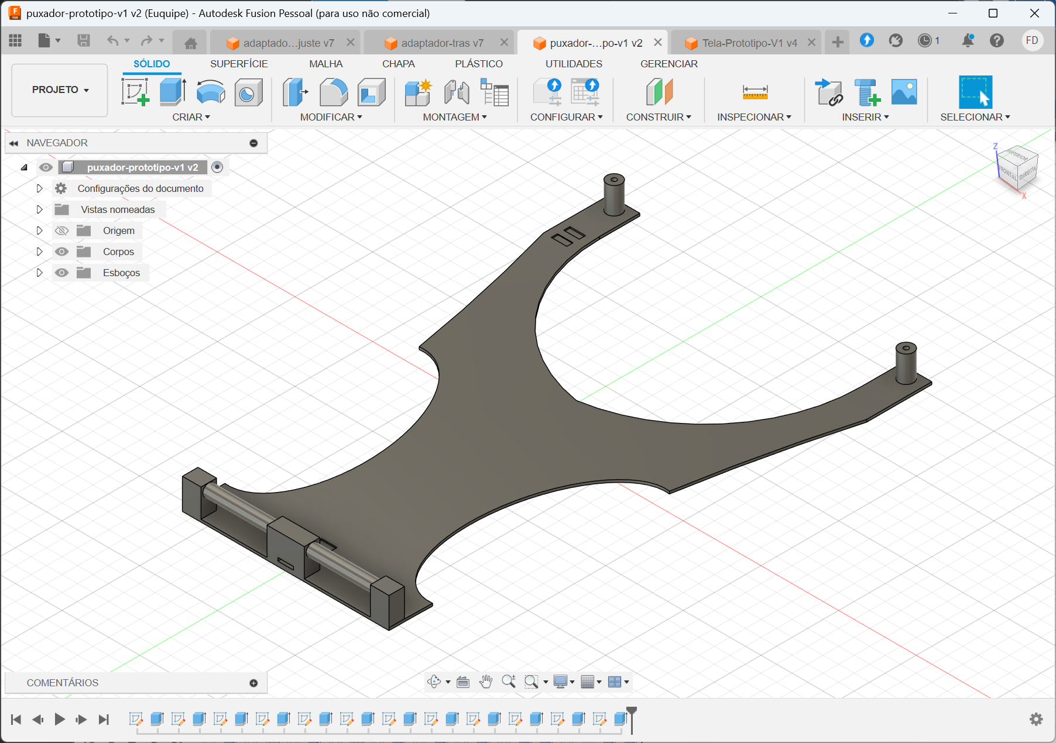
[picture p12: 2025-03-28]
images/case-handle.png

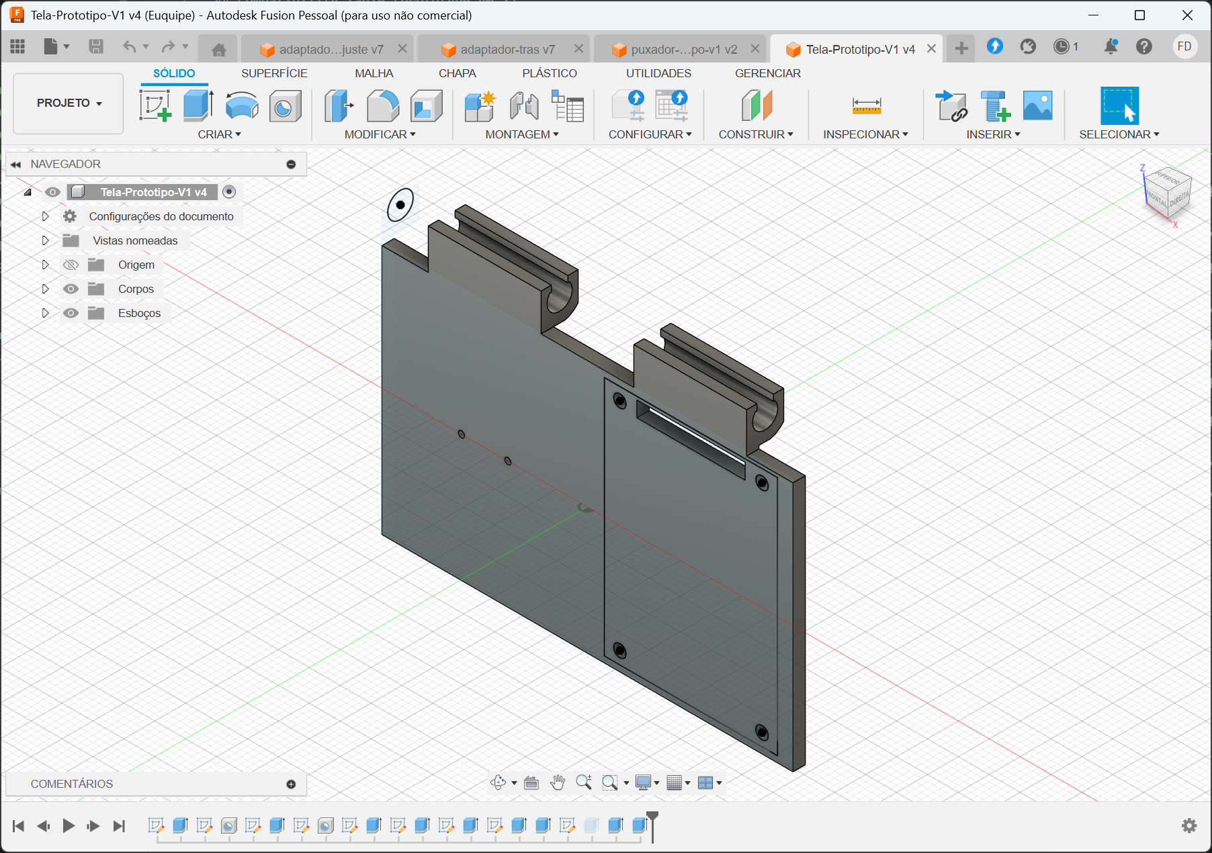
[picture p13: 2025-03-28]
images/case-screen.png

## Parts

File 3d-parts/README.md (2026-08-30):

# 3d parts for a Case

We've designed 3D case parts inspired by the Game Genie. There is a version for the front-loader and top-loader 72pin NES. 

On 2026-08 mi213 brought us better designs (you will need his board2 pcb with smd components)

## License

These files are licensed for non-commercial use (CC-BY-NC-4.0) since they were created using Autodesk Fusion under a non-commercial license. However, we may recreate them in an open-source CAD program in the future to allow for a more permissive license.

## Files

- stl files – Ready-to-print models

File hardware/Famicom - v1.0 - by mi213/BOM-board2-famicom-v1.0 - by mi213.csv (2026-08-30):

ID | Name | Designator | Quantity | Supplier | Supplier Part | link
1 | LCD | LCD1 | 1
2 | ESP32-C3-SUPER-MINI | U1 | 1
3 | 10uF | C1 | 1 | LCSC | C47023101 | https://www.lcsc.com/product-detail/C47023101.html?s_z=n_q_C47023101&globalKeyword=C47023101
4 | red | LED1 | 1 | LCSC | C965860 | https://www.lcsc.com/product-detail/C965860.html?s_z=n_q_C965860&globalKeyword=C965860
5 | green | LED2 | 1 | LCSC | C965863 | https://www.lcsc.com/product-detail/C965863.html?s_z=n_q_C965863&globalKeyword=C965863
6 | 1kΩ | R1 | 1 | LCSC | C22548 | https://www.lcsc.com/product-detail/C22548.html?s_z=n_q_C22548&globalKeyword=C22548
7 | 10kΩ | R2 | 1 | LCSC | C98220 | https://www.lcsc.com/product-detail/C98220.html?s_z=n_q_C98220&globalKeyword=C98220
8 | 100Ω | R3,R4 | 2 | LCSC | C122970 | https://www.lcsc.com/product-detail/C122970.html?s_z=n_q_C122970&globalKeyword=C122970
9 | 2700Hz | BUZZER1 | 1 | LCSC | C96127 | https://www.lcsc.com/product-detail/C96127.html?s_z=n_q_C96127&globalKeyword=C96127
10 | TS-1009B-05026 COPY | SW1 | 1 | LCSC | C6915252 | https://www.lcsc.com/product-detail/C6915252.html?s_z=n_q_C6915252&globalKeyword=C6915252
11 | BC847 | Q1 | 1 | LCSC | C475630 | https://www.lcsc.com/product-detail/C475630.html?s_z=n_q_C475630&globalKeyword=C475630
12 | FFC/FPC Con | FPC1 | 1 | LCSC | C2979162 | https://www.lcsc.com/product-detail/C2979162.html?s_z=n_q_C2979162&globalKeyword=C2979162
13 | Female Header | H1 | 1 | LCSC | C42379199 | https://www.lcsc.com/product-detail/C42379199.html?s_z=n_q_C42379199&globalKeyword=C42379199

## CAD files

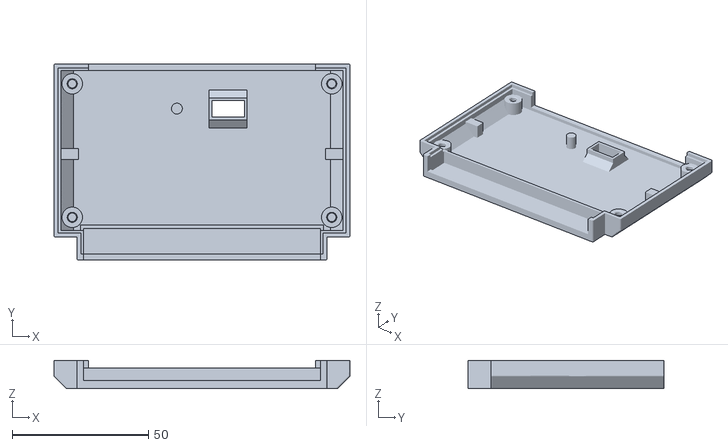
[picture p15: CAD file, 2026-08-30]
3d-parts/STL/Famicom - 60pin/20260811 - mi213 design/2.0-famicom-board1-top.stl
108.6 x 72.0 x 10.4

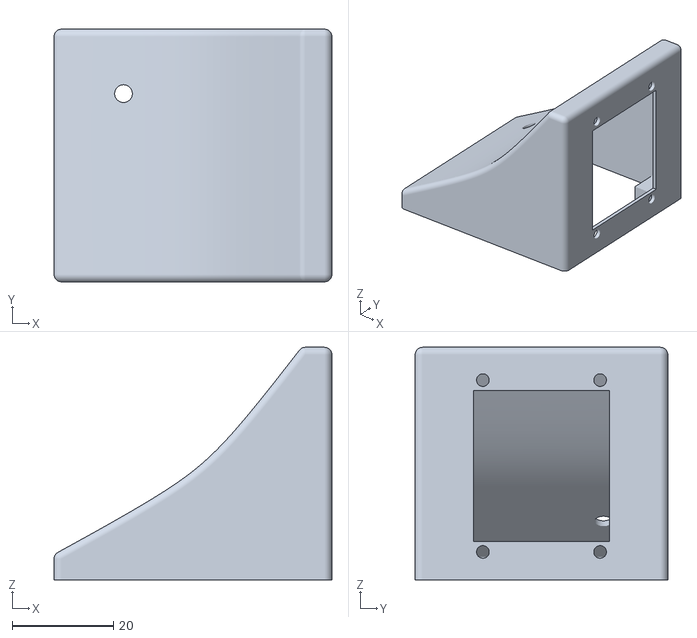
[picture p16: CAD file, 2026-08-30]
3d-parts/STL/NES - 72pin/20250911 - odelot design/front-loader/1.0-front-loader-board2-case.stl
55.0 x 50.0 x 46.0

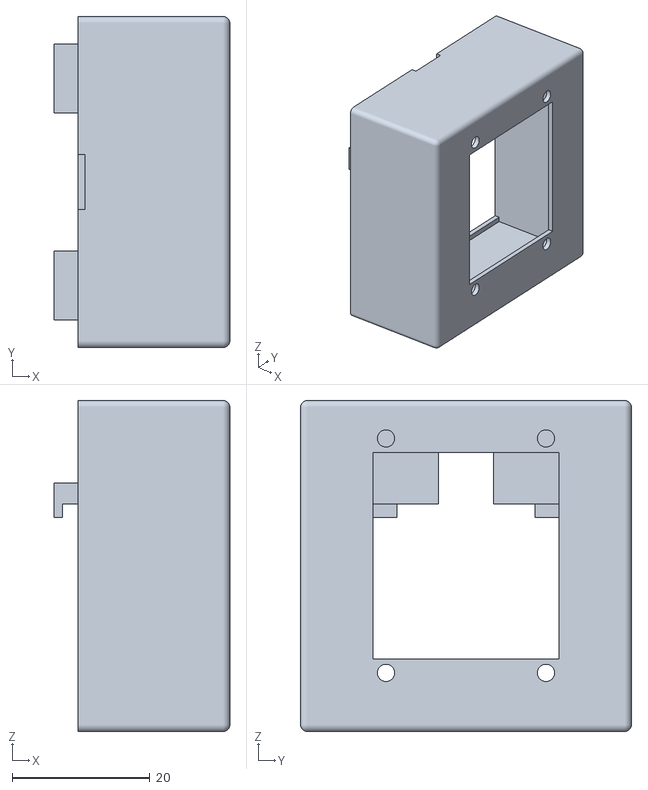
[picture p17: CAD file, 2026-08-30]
3d-parts/STL/NES - 72pin/20250911 - odelot design/top-loader/1.0-top-loader-board2-case.stl
25.5 x 48.0 x 48.0

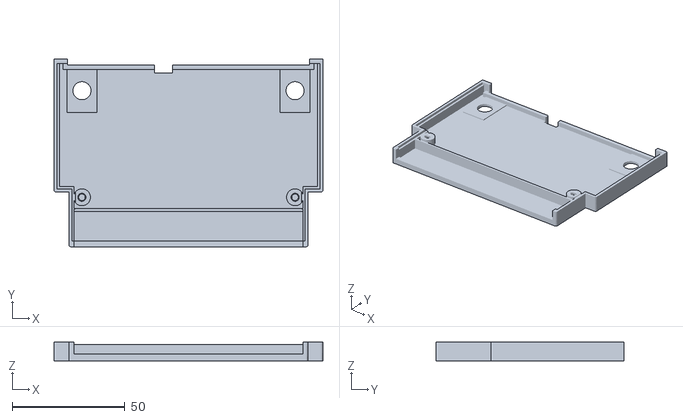
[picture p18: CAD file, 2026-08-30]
3d-parts/STL/NES - 72pin/20260811 - mi213 design/front-loader/2.0-front-loader-board1-top.stl
119.3 x 83.2 x 8.40

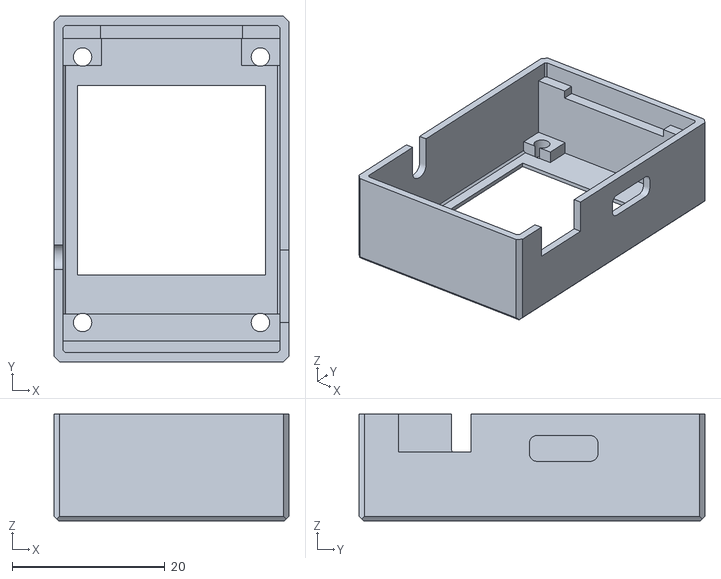
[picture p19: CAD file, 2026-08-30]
3d-parts/STL/Famicom - 60pin/20260811 - mi213 design/2.0-famicom-board2-case.stl
30.8 x 45.3 x 14.0

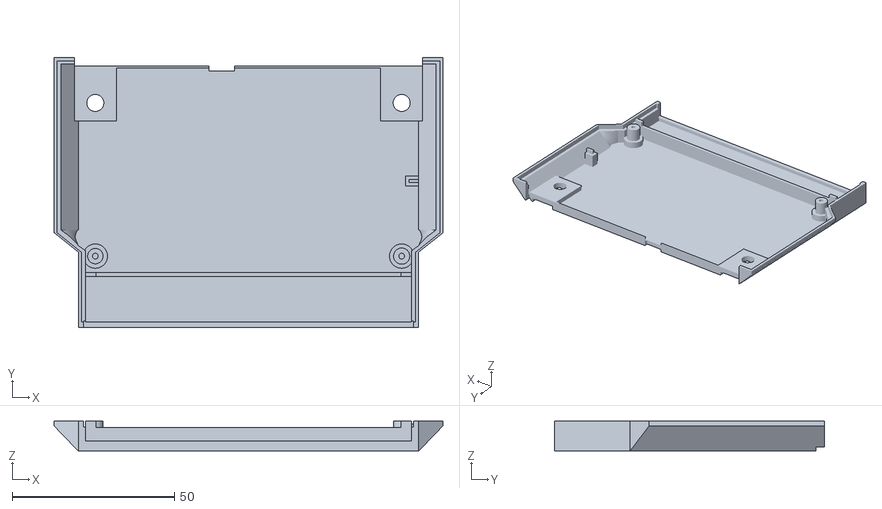
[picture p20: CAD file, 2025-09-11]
3d-parts/STL/NES - 72pin/20250911 - odelot design/front-loader/1.0-front-loader-board1-top.stl
120.0 x 83.2 x 9.25

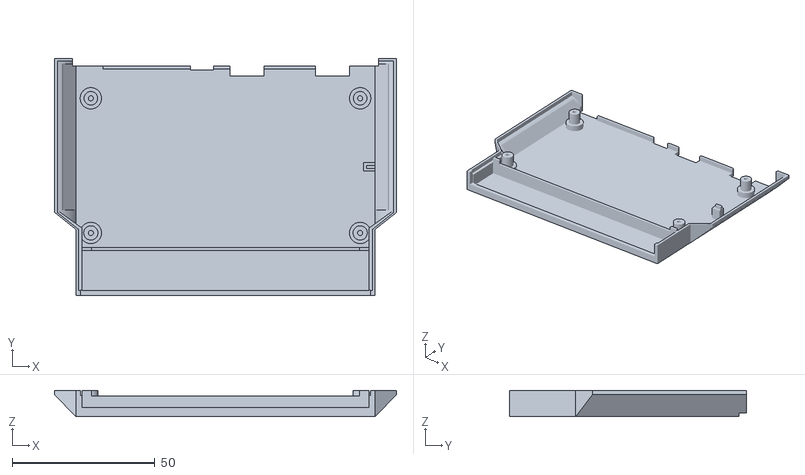
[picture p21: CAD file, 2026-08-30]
3d-parts/STL/NES - 72pin/20250911 - odelot design/top-loader/1.0-top-loader-board1-top.stl
120.0 x 83.2 x 9.25

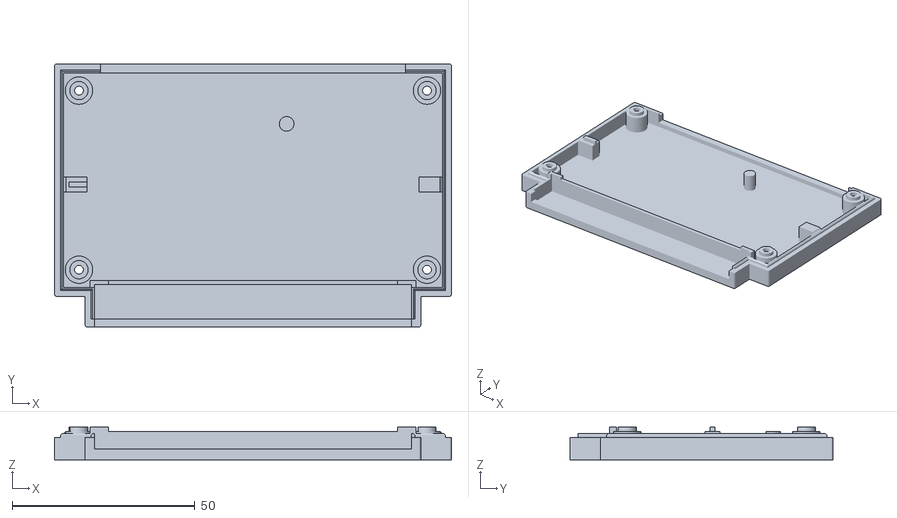
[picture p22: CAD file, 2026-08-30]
3d-parts/STL/Famicom - 60pin/20260811 - mi213 design/2.0-famicom-board1-bottom.stl
108.6 x 72.0 x 9.00

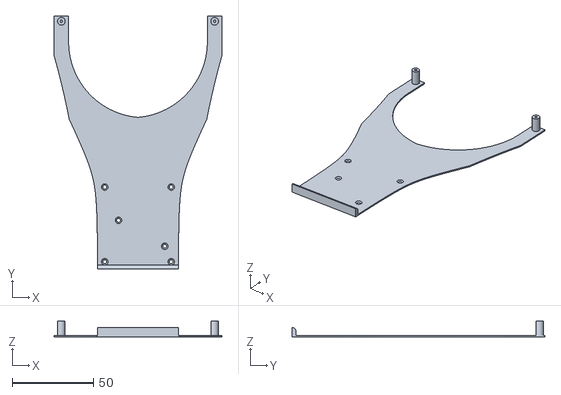
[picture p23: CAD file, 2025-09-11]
3d-parts/STL/NES - 72pin/20250911 - odelot design/front-loader/1.0-front-loader-bridge.stl
103.5 x 156.0 x 9.80

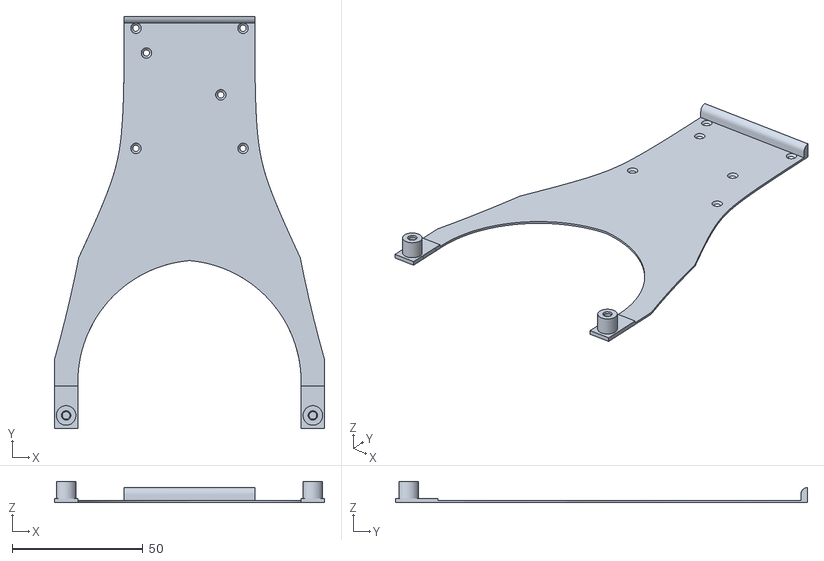
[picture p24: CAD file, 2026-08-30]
3d-parts/STL/NES - 72pin/20260811 - mi213 design/front-loader/2.0-front-loader-bridge.stl
103.5 x 157.8 x 8.20

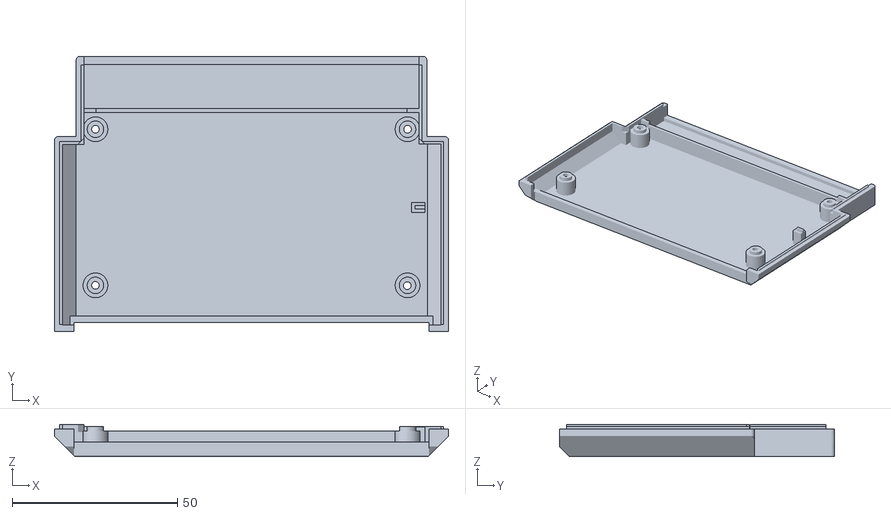
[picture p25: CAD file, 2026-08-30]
3d-parts/STL/NES - 72pin/20260811 - mi213 design/top-loader/2.0-top-loader-board1-bottom.stl
119.3 x 83.3 x 9.70

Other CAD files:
3d-parts/STL/NES - 72pin/20260811 - mi213 design/top-loader/2.0-top-loader-board1-top.stl
3d-parts/STL/NES - 72pin/20260811 - mi213 design/front-loader/2.0-front-loader-board1-bottom.stl

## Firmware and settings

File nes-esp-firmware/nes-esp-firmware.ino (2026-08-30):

/**********************************************************************************
                    NES RA Adapter - ESP32 Firmware

   This project is the ESP32 firmware for the NES RA Adapter, a device that connects
   to an NES console and enables users to connect to the RetroAchievements server to
   unlock achievements in games played on original hardware.

   The ESP32 provides Internet connectivity to the NES and also manages a TFT screen
   to display unlocked achievements, along with a buzzer for sound effects. It stores
   Wi-Fi and RA credentials in EEPROM and allows users to configure settings via a
   smartphone connected to the ESP32's access point. Users can reset the configuration
   by holding the reset button for 5 seconds during startup. Additionally, it utilizes
   LittleFS to store a CRC32-to-MD5 hash table (for cartridge identification) and game
   images. The firmware communicates with a Raspberry Pi Pico through Serial0 to retrieve
   the game CRC, send HTTP requests to RetroAchievements, and forward HTTP responses.
   Finally, it orchestrates the opening and closing of the bus between the NES and the
   cartridge by controlling analog switches.

   Date:             2026-07-19
   Version:          1.4
   By odelot

   Arduino IDE ESP32 Boards: v3.0.7

   Libs used:
   WifiManager: https://github.com/tzapu/WiFiManager v2.0.17
   PNGdec: https://github.com/bitbank2/PNGdec v1.1.2
   TFT_eSPI lib: https://github.com/Bodmer/TFT_eSPI v2.5.43
   ESP Async WebServer: https://github.com/ESP32Async/ESPAsyncWebServer v.3.7.6
   Async TCP: https://github.com/ESP32Async/AsyncTCP v3.4.0

   Compiled with Arduino IDE 2.3.4

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
**********************************************************************************/

/*********************************************************************************
* FEATURE FLAGS
**********************************************************************************/

#define ENABLE_RESET 1

/**
 * defines to use a aws lambda function to shrink the JSON response with the list of achievements
 * remember: you need to deploy the lambda and inform its URL
 */

#define ENABLE_SHRINK_LAMBDA 0 // 0 - disable / 1 - enable
#define SHRINK_LAMBDA_URL "https://xxxxxxxxxx.execute-api.us-east-1.amazonaws.com/default/NES_RA_ADAPTER?"

/**
 enable internal web app (comment to disable)
*/

#define ENABLE_INTERNAL_WEB_APP_SUPPORT

/**
* enable LCD (comment to disable)
*/
#define ENABLE_LCD

/**
* flip screen upside down
*/
#define FLIP_SCREEN

#include <WiFiManager.h>
#include <EEPROM.h>

#include <StreamString.h>
#include <WiFi.h>
#include <HTTPClient.h>
#include <time.h>
#include "HardwareSerial.h"
#include "LittleFS.h"
#include <esp_sleep.h>
#include <esp_system.h>
#include <esp_wifi.h>
#include <driver/uart.h>
#include <ESPmDNS.h>
#include <ESPAsyncWebServer.h>
#include <Wire.h>
#include <Ticker.h>
#include "CharBufferStream.h"
#include "JsonCleaner.h"
#include "PatchStreamFilter.h"

#ifdef ENABLE_LCD
  #include <PNGdec.h>
  #include "SPI.h"
  #include <TFT_eSPI.h>
#endif

#define VERSION "1.1"

/**
 * defines for the LittleFS
 */
#define FileSys LittleFS
#define FORMAT_LITTLEFS_IF_FAILED true

/**
 * defines for the EEPROM
 * Real usage: ~100 bytes (2 ID + 1 flag + 1 user_len + ~32 user + 1 pass_len + ~64 pass)
 */
#define EEPROM_SIZE 256
#define EEPROM_ID_1 142
#define EEPROM_ID_2 208

/**
 * defines for the analog switch
 */
#define ANALOG_SWITCH_PIN 3
#define ANALOG_SWITCH_ENABLE_BUS HIGH
#define ANALOG_SWITCH_DISABLE_BUS LOW

/**
 * defines for sending big serial data into chunks with a delay
 */
#define SERIAL_COMM_CHUNK_SIZE 32
#define SERIAL_COMM_TX_DELAY_MS 5

#define SERIAL_MAX_PICO_BUFFER 102400

/**
 * Ceiling for the Pico's estimated peak heap need during rc_client load
 * (payload + parsed triggers + rich presence + strings - see
 * estimate_pico_load_need_buffer). The Pico has ~191KB of heap; 168KB leaves
 * room for API transients and fragmentation. Calibrated so SMB3's full set
 * (need ~157KB, known to fit) passes untouched while FF3's (need ~353KB,
 * known to PANIC) gets trimmed.
 */
#define PICO_LOAD_LIMIT 172032
/**
 * defines for the fifo used to store achievements to be showed on screen
 */
#define ACHIEVEMENTS_FIFO_SIZE 5

/**
 * defines for the png decoder
 */
#define MAX_IMAGE_WIDTH 240

/**
 * defines for the LCD
 */
#define LCD_BRIGHTNESS_PIN 7

/**
 * defines for status led
 */
#define LED_STATUS_RED_PIN 6
#define LED_STATUS_GREEN_PIN 5

/**
 * defines for the buzzer
 */

#define NOTE_CS6 1109
#define NOTE_D6 1175
#define NOTE_D5 587
#define NOTE_C4 262
#define NOTE_G4 392
#define NOTE_G5 784
#define NOTE_A5 880
#define NOTE_B5 988
#define NOTE_E6 1319
#define NOTE_G6 1568
#define NOTE_C7 2093
#define NOTE_D7 2349
#define NOTE_E7 2637
#define NOTE_F7 2794
#define NOTE_G7 3136
#define NOTE_B4   494
#define NOTE_FS5  740
#define NOTE_C5  523
#define NOTE_GS4 415
#define NOTE_AS4 466
#define NOTE_CS6 1109
#define NOTE_DS6 1245
#define NOTE_F6  1397
#define NOTE_FS6 1480
#define NOTE_GS6 1661
#define NOTE_A6  1760
#define NOTE_AS6 1865
#define NOTE_B6  1976


#define SOUND_PIN 10

/**
 * defines for the reset button
 */

// time that reset button should be pressed to kick off reset operation
#define RESET_PRESSED_TIME 5000L

// pin to the reset button
#define RESET_PIN 8

// types for http request
typedef enum HttpRequestMethod
{
  GET = 0,
  POST = 1
};

typedef enum HttpRequestResult
{
  HTTP_SUCCESS = 0,
  HTTP_ERR_NO_WIFI = -1,
  HTTP_ERR_REQUEST_FAILED = -2,
  HTTP_ERR_HTTP_4XX = -3,
  HTTP_ERR_TIMEOUT = -4,
  HTTP_ERR_REPONSE_TOO_BIG = -5,
};

// RA login outcome - tells bad credentials apart from network/RA outage so the
// caller can decide whether to save credentials and what to show on the screen
typedef enum LoginResult
{
  LOGIN_OK = 0,
  LOGIN_ERR_INVALID_CREDENTIALS = 1,
  LOGIN_ERR_NETWORK = 2,
};

// Device state machine states
typedef enum DeviceState {
  STATE_IDENTIFY_CARTRIDGE = 0,
  STATE_WAITING_CRC = 1,
  STATE_CRC_FOUND = 2,
  STATE_WATCHING = 3,
  STATE_IDLE = 128,
  STATE_ERROR_CONNECTIVITY = 198,
  STATE_ERROR_RESPONSE_TOO_BIG = 199,
  STATE_ERROR_LOGIN_FAILED = 253,
  STATE_ERROR_CARTRIDGE_NOT_FOUND = 254,
  STATE_UNINITIALIZED = 255
} DeviceState;

// Check if state is an error state
inline bool isErrorState(DeviceState s) {
  return s >= STATE_ERROR_CONNECTIVITY;
}

// Get error message for a given state
const char* getStateErrorMessage(DeviceState s) {
  switch(s) {
    case STATE_ERROR_CONNECTIVITY:
      return "Connectivity Error";
    case STATE_ERROR_RESPONSE_TOO_BIG:
      return "RA response is too big";
    case STATE_ERROR_LOGIN_FAILED:
      return "Could not log in RA!";
    case STATE_ERROR_CARTRIDGE_NOT_FOUND:
      return "Cartridge not identified";
    default:
      return "Unknown error";
  }
}

// type to store the achievements to be showed on screen
typedef struct
{
  uint32_t id;
  String title;
  String url;
} achievements_t;

// type to store the achievement fifo
typedef struct
{
  achievements_t buffer[ACHIEVEMENTS_FIFO_SIZE];
  int head;
  int tail;
  int count;
} achievements_FIFO_t;

// types for LED control

enum LedMode {
  LED_OFF,
  LED_ON,
  LED_BLINK_SLOW,
  LED_BLINK_MEDIUM,
  LED_BLINK_FAST
};

enum LedColor {
  LED_RED,
  LED_GREEN,
  LED_YELLOW  
};

struct Led {
  uint8_t pin;
  LedMode mode;
  bool state; // HIGH ou LOW atual
  Ticker ticker;
};

// Forward declarations for functions using custom types
// (needed because Arduino IDE auto-generates prototypes before type definitions)
void updateLed(Led* led);
void configureTicker(Led* led);
void setSemaphore(LedMode mode, LedColor color);
void fifo_init(achievements_FIFO_t *fifo);
bool fifo_is_empty(achievements_FIFO_t *fifo);
bool fifo_is_full(achievements_FIFO_t *fifo);
bool fifo_enqueue(achievements_FIFO_t *fifo, achievements_t value);
bool fifo_dequeue(achievements_FIFO_t *fifo, achievements_t *value);
void show_achievement(achievements_t achievement);
void redraw_achievement_screen(const achievements_t &achievement, uint16_t bgColor);


// global variables for LED control
Led ledRed   = {LED_STATUS_RED_PIN, LED_OFF, false, Ticker()};
Led ledGreen = {LED_STATUS_GREEN_PIN, LED_OFF, false, Ticker()};


#ifdef ENABLE_LCD
// global variables for the PNG decoder - pointer to save memory during patch download
PNG* png = nullptr;
int16_t x_pos = 0;
int16_t y_pos = 0;
File png_file;

// global variables for the TFT screen
TFT_eSPI tft = TFT_eSPI();
#endif

// global variables for the achievements fifo
achievements_FIFO_t achievements_fifo;

// custom html and parameters for the configuration portal
const char head[] PROGMEM = "<style>#l,#i,#z{text-align:center}#i,#z{margin:15px auto}button{background-color:#0000FF;}#l{margin:0 auto;width:100%; font-size: 28px;}p{margin-bottom:-5px}[type='checkbox']{height: 20px;width: 20px;}</style><script>var w=window,d=document,e=\"password\";function cc(){z=gE(this.w);z.type!=e?z.type=e:z.type='text';z.focus();}function iB(a,b,c){a.insertBefore(b,c)}function gE(a){return d.getElementById(a)}function cE(a){return d.createElement(a)};\"http://192.168.1.1/\"==w.location.href&&(w.location.href+=\"wifi\");</script>\0";
const char html_p1[] PROGMEM = "<p id='z' style='width: 80%;'>Enter the RetroAchievements credentials below:</p>\0";
const char html_p2[] PROGMEM = "<p>&#8226; RetroAchievements user name: </p>\0";
const char html_p3[] PROGMEM = "<p>&#8226; RetroAchievements user password: </p>\0";
const char html_s[] PROGMEM = "<script>gE(\"s\").required=!0;l=cE(\"div\");l.innerHTML=\"NES RetroAchievements Adapter\",l.id=\"l\";m=d.body.childNodes[0];iB(m,l,m.childNodes[0]);p=cE(\"p\");p.id=\"i\",p.innerHTML=\"Choose the network you want to connect with:\",iB(m,p,m.childNodes[1]),a=d.createTextNode(\" show \"+e),sp=(s=d.getElementById(\"up\").nextSibling).parentNode,(c1=d.createElement(\"input\")).type=\"checkbox\",c1.onclick=cc,c1.w=\"up\",iB(sp,c1,s),iB(sp,a,s);</script>\0";

// ws variables
#ifdef ENABLE_INTERNAL_WEB_APP_SUPPORT
AsyncWebServer* server = nullptr;
AsyncWebSocket* ws = nullptr;
uint32_t last_ws_cleanup = millis();
AsyncWebSocketClient *ws_client = NULL;
bool websocket_initialized = false;
#endif

// global variables for the state machine
DeviceState state = STATE_UNINITIALIZED;

// URL base for RetroAchievements API
const char* base_url = "https://retroachievements.org/dorequest.php?";

// Achievement tracking for display
uint16_t total_achievements = 0;
uint16_t unlocked_achievements = 0;

// global variables for storing states, timestamps and useful information
String ra_user_token;

// Buffer fixo para comunicação serial com o Pico (evita fragmentação de memória)
// Reduzido para economizar RAM - comandos típicos são < 512 bytes
#define SERIAL_BUFFER_SIZE 768
char serial_buffer[SERIAL_BUFFER_SIZE];
size_t serial_buffer_len = 0;

// Flexible buffer for large HTTP responses 
#define LARGE_BUFFER_SIZE 102400 // 100 KB 
#define SMALL_BUFFER_SIZE 10240 // 10 KB
CharBufferStream response;
// Streaming cleaner for patch downloads - lets the raw response exceed the
// buffer as long as the cleaned result fits (staging allocated per download)
PatchStreamFilter patch_filter;
// HTTP client global to reuse SSL buffers (avoids fragmentation)
NetworkClientSecure globalSecureClient;
HTTPClient globalHttpClient;
bool httpClientInitialized = false;

// Cartridge MD5 - use fixed buffer instead of String to avoid fragmentation
char md5_global[34] = {0};

String game_name;
String game_image;
String game_id;
String game_session;
bool go_back_to_title_screen = false;

// set by GAME_BEATEN, consumed by the main loop once the achievement that
// completed the game is on screen
bool pending_game_beaten = false;

// last achievement drawn by show_achievement - the BEATEN celebration runs
// after it returns and needs it to flash that same screen
achievements_t last_shown_achievement;
bool has_last_shown_achievement = false;

// the "** BEATEN! **" banner is covering the splash footer and must be
// repainted when we go back to the title screen (unlike MASTERED, the player
// keeps playing after beating the game)
bool beaten_banner_visible = false;
bool already_showed_title_screen = false;
long go_back_to_title_screen_timestamp;
unsigned long last_wifi_status_update = 0;

/**
 * functions related to LED status and control
 */

// function called by the ticker to update the LED state
void updateLed(Led* led) {
  switch (led->mode) {
    case LED_OFF:
      led->state = false;
      digitalWrite(led->pin, LOW);
      break;

    case LED_ON:
      led->state = true;
      digitalWrite(led->pin, HIGH);
      break;

    case LED_BLINK_SLOW:
    case LED_BLINK_MEDIUM:
    case LED_BLINK_FAST:
      led->state = !led->state;
      digitalWrite(led->pin, led->state);
      break;
  }
}

// configure the LED ticker based on the mode
void configureTicker(Led* led) {
  led->ticker.detach();  // Para evitar duplicatas

  float interval = 0;

  switch (led->mode) {
    case LED_BLINK_SLOW:   interval = 0.9; break;
    case LED_BLINK_MEDIUM: interval = 0.6; break;
    case LED_BLINK_FAST:   interval = 0.3; break;
    case LED_ON:
    case LED_OFF:
      updateLed(led);  // atualiza o estado imediatamente
      return;
  }

  led->ticker.attach(interval, updateLed, led);
}

// set the LED mode and color
void setSemaphore (LedMode mode, LedColor color) {
  ledRed.mode = LED_OFF;
  ledGreen.mode = LED_OFF;
  switch (color) {
    case LED_RED:
      ledRed.mode = mode;
      break;
    case LED_GREEN:
      ledGreen.mode = mode;      
      break;
    case LED_YELLOW:
      ledRed.mode = mode;
      ledGreen.mode = mode;
      break;
  }
  configureTicker(&ledRed);
  configureTicker(&ledGreen);
}


/**
 * functions to identify the cartridge
 */
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
void loop()
{

#ifdef ENABLE_INTERNAL_WEB_APP_SUPPORT
  if (websocket_initialized && ws != nullptr) {
    uint32_t delta_ws_cleanup = millis() - last_ws_cleanup;
    last_ws_cleanup = millis();
    if (delta_ws_cleanup > 1000)
    {
      ws->cleanupClients();
    }
  }

  // #TODO last ping was too long ago, closes the connection
#endif

  // Update WiFi status every 10 seconds after title screen was shown
  if (already_showed_title_screen && (millis() - last_wifi_status_update > 10000))
  {
    last_wifi_status_update = millis();
    showWifiStatus();
  }

  long go_back_to_title_delta_timestamp = millis() - go_back_to_title_screen_timestamp;
  // check if we can go back to the title screen after showing the achievement for 15 seconds
  if (go_back_to_title_screen == true && go_back_to_title_delta_timestamp > 15000)
  {
    go_back_to_title_screen = false;
    if (fifo_is_empty(&achievements_fifo))
    {

      show_title_screen();
      // show_title_screen does not repaint below the game image, so the BEATEN
      // banner would survive into the title screen - drop it and put the
      // original footer back
      if (beaten_banner_visible)
      {
        clear_beaten_banner();
      }
    }
  }

  // handle errors during the cartridge identification - unified error handling
  if (isErrorState(state))
  {
    setSemaphore(LED_BLINK_FAST, LED_RED);
    const char* errorMsg = getStateErrorMessage(state);
    print_line(errorMsg, 1, 2);
    
    if (state == STATE_ERROR_CONNECTIVITY) {
      print_line("It's not recording achievs", 2, 2);
    }
    
    print_line("Turn off the console", 4, 2);
    play_error_sound();
    state = STATE_IDLE; // do nothing - it will not enable the BUS, so the game will not boot
  }

  // handle the cartridge identification
  if (state == STATE_IDENTIFY_CARTRIDGE)
  {
    setSemaphore(LED_BLINK_FAST, LED_GREEN);
    print_line("Identifying cartridge...", 1, 1);

    Serial0.print(F("READ_CRC\r\n")); // send command to read cartridge crc
    Serial.print(F("READ_CRC\r\n"));  // send command to read cartridge crc
    delay(250);
    state = STATE_WAITING_CRC;

    // USEFUL FOR TESTING - FORCING SOME GAME, IN THIS CASE, RC PRO AM
    // md5 = "2178cc3772b01c9f3db5b2de328bb992";
    // state = STATE_CRC_FOUND;
  }

  // inform the pico to start the process to watch the BUS for memory writes
  if (state == STATE_CRC_FOUND)
  {
    Serial0.print(F("START_WATCH\r\n"));
    Serial.print(F("START_WATCH\r\n"));
    state = STATE_WATCHING;
  }

  // if there is some achievement to be shown, show it
  if (fifo_is_empty(&achievements_fifo) == false && Serial.available() == 0 && go_back_to_title_screen == false) // show achievements
  {
    achievements_t achievement;
    fifo_dequeue(&achievements_fifo, &achievement);
    show_achievement(achievement);
  }
  // celebrate the beaten game only after every pending achievement has been
  // shown, so the banner lands on top of the unlock that earned it
  else if (pending_game_beaten && fifo_is_empty(&achievements_fifo) && Serial0.available() == 0)
  {
    celebrate_game_beaten();
  }

  // handle the serial communication with the pico - usando buffer fixo
  while (Serial0.available() > 0)
  {
    // Read only up to available space
    size_t available_space = SERIAL_BUFFER_SIZE - serial_buffer_len - 1;
    if (available_space > 0) {
      size_t bytes_read = Serial0.readBytes(serial_buffer + serial_buffer_len, available_space);
      serial_buffer_len += bytes_read;
      serial_buffer[serial_buffer_len] = '\0'; // null-terminate
    }
    
    // Check for overflow
    if (serial_buffer_len >= SERIAL_BUFFER_SIZE - 1)
    {
      serial_buffer_len = 0;
      serial_buffer[0] = '\0';
      Serial0.print(F("BUFFER_OVERFLOW\r\n"));
      Serial.print(F("BUFFER_OVERFLOW\r\n"));
      continue;
    }

    // Process complete commands (terminated by \r\n)
    int crlf_pos;
    while ((crlf_pos = find_crlf(serial_buffer, serial_buffer_len)) >= 0)
    {
      // We have a complete command
      size_t cmd_len = crlf_pos; // does not include \r\n
      
      // Dispatch to the appropriate handler
      if (starts_with(serial_buffer, cmd_len, "REQ=")) {
        handle_req_command(serial_buffer + 4, cmd_len - 4);
      }
      else if (starts_with(serial_buffer, cmd_len, "READ_CRC=")) {
        handle_read_crc_command(serial_buffer + 9, cmd_len - 9);
      }
      else if (starts_with(serial_buffer, cmd_len, "A=")) {
        handle_achievement_command(serial_buffer + 2, cmd_len - 2);
      }
      else if (starts_with(serial_buffer, cmd_len, "GAME_INFO=")) {
        handle_game_info_command(serial_buffer + 10, cmd_len - 10);
      }
      else if (starts_with(serial_buffer, cmd_len, "ACH_SUMMARY=")) {
        handle_ach_summary_command(serial_buffer + 12, cmd_len - 12);
      }
      else if (starts_with(serial_buffer, cmd_len, "GAME_BEATEN")) {
        handle_game_beaten_command();
      }
      else if (starts_with(serial_buffer, cmd_len, "NES_RESETED")) {
        handle_nes_reset_command();
      }
      else if (starts_with(serial_buffer, cmd_len, "C=")) {
#ifdef ENABLE_INTERNAL_WEB_APP_SUPPORT
        // Create temporary String only for websocket
        char temp[256];
        size_t temp_len = min(cmd_len, sizeof(temp) - 1);
        memcpy(temp, serial_buffer, temp_len);
        temp[temp_len] = '\0';
        send_ws_data(String(temp));
#endif
      }
      else if (starts_with(serial_buffer, cmd_len, "P=")) {
#ifdef ENABLE_INTERNAL_WEB_APP_SUPPORT
        char temp[256];
        size_t temp_len = min(cmd_len, sizeof(temp) - 1);
        memcpy(temp, serial_buffer, temp_len);
        temp[temp_len] = '\0';
        send_ws_data(String(temp));
#endif
      }
      else {
        Serial.print(F("UNKNOWN="));
        Serial.write(serial_buffer, cmd_len);
        Serial.println();
      }
      
      // Remove processed command from buffer (including \r\n)      
      size_t remove_len = crlf_pos + 2;
      if (remove_len < serial_buffer_len) {
        memmove(serial_buffer, serial_buffer + remove_len, serial_buffer_len - remove_len);
        serial_buffer_len -= remove_len;
      } else {
        serial_buffer_len = 0;
      }
      serial_buffer[serial_buffer_len] = '\0';
    }
  }
  yield();
}

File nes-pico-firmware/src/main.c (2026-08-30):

/**********************************************************************************
                NES RA Adapter - Raspberry Pi Pico Firmware

   This project is the Raspberry Pi Pico firmware for the NES RA Adapter, a device
   that connects to an NES console and enables users to connect to the RetroAchievements
   server to unlock achievements in games played on original hardware.

   The Pico firmware has two main responsibilities. The first is to read a portion of
   the cartridge to calculate the CRC and identify the game; the second is to monitor
   the bus for memory writes and process them using the rcheevos library.

    * Core 0 handles CRC calculation, executes the rcheevos routines, and manages serial
      communication with the ESP32 (primarily for Internet connectivity).

    * Core 1 monitors the bus using three PIO state machines and no DMA:
      - SM0 captures exactly one bus snapshot per CPU write cycle (sampled inside the
        data-valid window of M2 high) and core 1 drains the FIFO directly, updating
        static mirrors of the NES RAM and cartridge SRAM.
      - SM1 watches for reads of the NMI vector ($FFFA/$FFFB): a match marks the exact
        start of vblank, when core 1 takes an atomic snapshot of the mirrors and
        signals core 0 to run a rcheevos frame.
      - SM2 watches for reads of the RESET vector ($FFFC/$FFFD) to detect a console
        reset and reset the rcheevos runtime state.
      Writes to $4014 (OAM DMA) are kept as a vblank fallback for games that run with
      NMI disabled, and a timer-based fallback covers forced-blank periods.

    Inter-core communication is managed via a circular buffer. Please note that the available
    space for serial communication is limited to around 32KB, which restricts the size of
    the achievement list response.

   Date:             2026-07-12
   Version:          1.4
   By odelot

   Libs used:
   rcheevos: https://github.com/RetroAchievements/rcheevos

   Compiled with Pico SDK 1.5.1

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
**********************************************************************************/

#include <stdio.h>
#include <string.h>
#include <malloc.h>
#include <limits.h>
#include <math.h>

#include "pico/stdlib.h"
#include "pico/malloc.h"
#include "pico/multicore.h"
#include "pico/mutex.h"
#include "pico/time.h"
#include "hardware/gpio.h"
#include "hardware/uart.h"
#include "hardware/clocks.h"
#include "hardware/pio.h"
#include "hardware/structs/systick.h"
#include "hardware/timer.h"
#include "hardware/spi.h"
#include "hardware/i2c.h"
#include "hardware/adc.h"
#include "hardware/watchdog.h"

#include "memory-bus.pio.h"

#include "rc_runtime_types.h"
#include "rc_client.h"
#include "rc_client_internal.h"
#include "rc_api_info.h"
#include "rc_api_runtime.h"
#include "rc_api_user.h"
#include "rc_consoles.h"
#include "rc_hash.h"
#include "rc_version.h"
#include "rc_internal.h"

#define FIRMWARE_VERSION "1.4"

// run at 200mhz can save energy and need to be tested if it is stable - it saves ~0.010A
#define RUN_AT_200MHZ

#define BUS_PIO pio0
#define BUS_SM_WRITE 0 // one snapshot per CPU write cycle
#define BUS_SM_NMI 1   // NMI vector fetch watcher ($FFFA/$FFFB)
#define BUS_SM_RESET 2 // RESET vector fetch watcher ($FFFC/$FFFD)
#define BUS_SM_PPU 3   // PPU /RD quiescence watcher (ENABLE_PPU_RD_VBLANK)

// The M2 frame clock lives on pio1 so it never competes with BUS_SM_PPU for
// the last state machine of pio0 (both can be enabled at the same time).
#define M2_PIO pio1
#define M2_SM 0

#define UART_ID uart0
#define BAUD_RATE 115200

#define NES_D0 0
#define NES_D1 1
#define NES_D2 2
#define NES_D3 3
#define NES_D4 4
#define NES_D5 5
#define NES_D6 6
#define NES_D7 7

#define NES_A00 8
#define NES_A01 9
#define NES_A02 10
#define NES_A03 11
#define NES_A04 12
#define NES_A05 13
#define NES_A06 14
#define NES_A07 15

#define NES_A08 16
#define NES_A09 17
#define NES_A10 18
#define NES_A11 19
#define NES_A12 20
#define NES_A13 21
#define NES_A14 22

#define NES_M2 23     // F0
#define NES_ROMSEL 24 // F1
#define NES_RW 25     // F2

#define UART_TX_PIN 28 // GPIO pin for TX
#define UART_RX_PIN 29 // GPIO pin for RX

#define REFRESH_RATE_60_HZ // comment this line to compile to 50hz

#ifdef REFRESH_RATE_60_HZ
#define FRAME_TIME_US 16667 // 1000000 / 60 = 16666.6667
#else
#define FRAME_TIME_US 20000 // 1000000 / 50 = 20000
#endif

/**
 * M2 frame clock: exact frame pacing derived from the console's own clock.
 *
 * M2 (the CPU clock) and the PPU dot clock come from the same crystal, so a
 * video frame is an exact number of M2 cycles - expressed here as a fraction
 * because it is not an integer:
 *   NTSC: 262 scanlines * 341 dots = 89342 dots / 3 dots-per-cycle = 29780.667
 *   PAL:  312 scanlines * 341 dots = 106392 dots / 3.2             = 33247.5
 * Software walks the fraction with a Bresenham accumulator (see
 * m2_next_frame_cycles), so the long-run rate has NO drift at all.
 *
 * This replaces the free-running FRAME_TIME_US timer as the fallback for
 * stretches where the NMI vector is silent. The timer runs off the Pico's
 * crystal at 16667us against a real NTSC frame of 16639.2us: 27.8us of error
 * per frame, i.e. a whole frame gained every ~600 frames (~10s). M2 is the
 * console's own clock and never stops - not with rendering off, not with NMI
 * disabled, not during DMA - so it covers every case the other detectors miss.
 */
#ifdef REFRESH_RATE_60_HZ
#define M2_CYCLES_NUM 89342 // NTSC PPU dots per frame
#define M2_CYCLES_DEN 3     // NTSC PPU dots per CPU cycle
#else
#define M2_CYCLES_NUM 66495 // PAL: 106392 dots / 3.2 == 66495 / 2
#define M2_CYCLES_DEN 2
#endif

/**
 * While defined, the M2 frame clock is measured (VBM2 log line) but never
 * drives pacing - frames stay on the NMI path with the old timer fallback.
 * Use it to validate the clock on real hardware before trusting it: with the
 * cycles-per-frame fraction correct, the reported M2 period must match the
 * NMI period to within a few us and stay there indefinitely. Comment this out
 * to let the M2 clock replace the timer fallback.
 */
// #define M2_FRAME_CLOCK_SHADOW_ONLY

/**
 * enable internal web app support
 */

#define ENABLE_INTERNAL_WEB_APP_SUPPORT
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

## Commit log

2025-04-25 avoid lose ram for the config step
    [nes-esp-firmware.ino]
2025-05-12 Fim da campanha de doação - MUITO OBRIGADO
2025-06-14 fix typos and lambda usage
    [nes-esp-firmware.ino]
2025-06-25 fix bug - first achiev with flags = 5
    [nes-esp-firmware.ino]
2025-09-11 release v1.0
    [1.0-front-loader-board1-front.stl, 1.0-front-loader-bridge.stl, case-cartridge-back.f3d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]
2025-09-24 Update total cost and add 3D print parts set
2025-09-24 Update total cost and add 3D print parts
2025-10-20 Add PCB thickness details for NES cartridges
    Added information about PCB thickness for NES cartridges.
2025-10-20 Atualiza README com detalhes sobre espessura das PCBs
    Adiciona informações sobre a espessura das placas de circuito impresso dos cartuchos de NES e GameGenie.
2025-10-21 Update README with assembly video and board details
    Added assembly video guide and improved formatting for board descriptions.
2025-10-21 Add video guide link to README.pt-br.md
    Added a video guide link for assembly instructions.
2026-02-01 feature: v1.1 - save ram on ESP32
2026-02-01 fix: increase small buffer - startsession can be > 1Kb
    [nes-esp-firmware.ino]
2026-02-14 Update README with assembly video and notes
    Added assembly video guide and additional assembly notes.
2026-02-14 Atualiza README com detalhes do adaptador e montagem
    Adiciona informações sobre o adaptador e guia de montagem.
2026-03-24 feature: v1.2 alpha - new frame heuristic
2026-05-04 fix castlevania reading problem
    [main.c]
2026-05-14 refactor: replace circular memory buffer with static NES RAM/SRAM mirroring and atomic snapshots
    [main.c]
2026-05-15 improve pico memory efficiency
2026-07-12 feature: detect reset and improve vblank detection
    [main.c]
2026-07-19 feature: clean json during the payload download to save ram (ff3 fix)
    [JsonCleaner.h, PatchStreamFilter.h, nes-esp-firmware.ino]
2026-07-19 fix: memory mapping was not getting A15 (from /ROMSEL)
    [main.c]
2026-08-30 fix: detect wrong credentials
    [nes-esp-firmware.ino]
2026-08-30 feature: v1.4 release
    [1.0-front-loader-board1-top.stl, 1.0-front-loader-board2-case.stl, 1.0-front-loader-bridge.stl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]

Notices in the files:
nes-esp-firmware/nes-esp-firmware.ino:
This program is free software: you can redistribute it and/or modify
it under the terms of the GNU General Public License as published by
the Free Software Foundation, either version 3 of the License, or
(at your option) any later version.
